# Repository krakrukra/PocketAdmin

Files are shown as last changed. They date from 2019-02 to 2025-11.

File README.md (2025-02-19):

# PocketAdmin  
  
#### Русская версия документации доступна [здесь](https://github.com/krakrukra/PocketAdmin/blob/master/extra/wiki/rus/README.md)  
  
This is a keystroke injection device (also called badusb). It is similar to a well-known  
[USB rubber ducky](https://shop.hak5.org/products/usb-rubber-ducky-deluxe) made by hak5, has rather extensive functionality, lower price  
and is also completely open source. It looks and feels like an ordinary USB flash drive,  
but acts as a keyboard that types in a preprogrammed payload. This payload can do anything  
from configuring a network to installing a reverse shell, since the device can basically  
do whatever an admin can with a terminal, but taking only a few seconds. This makes  
it a very powerful tool for automating sysadmin tasks or use in penetration testing.  
  
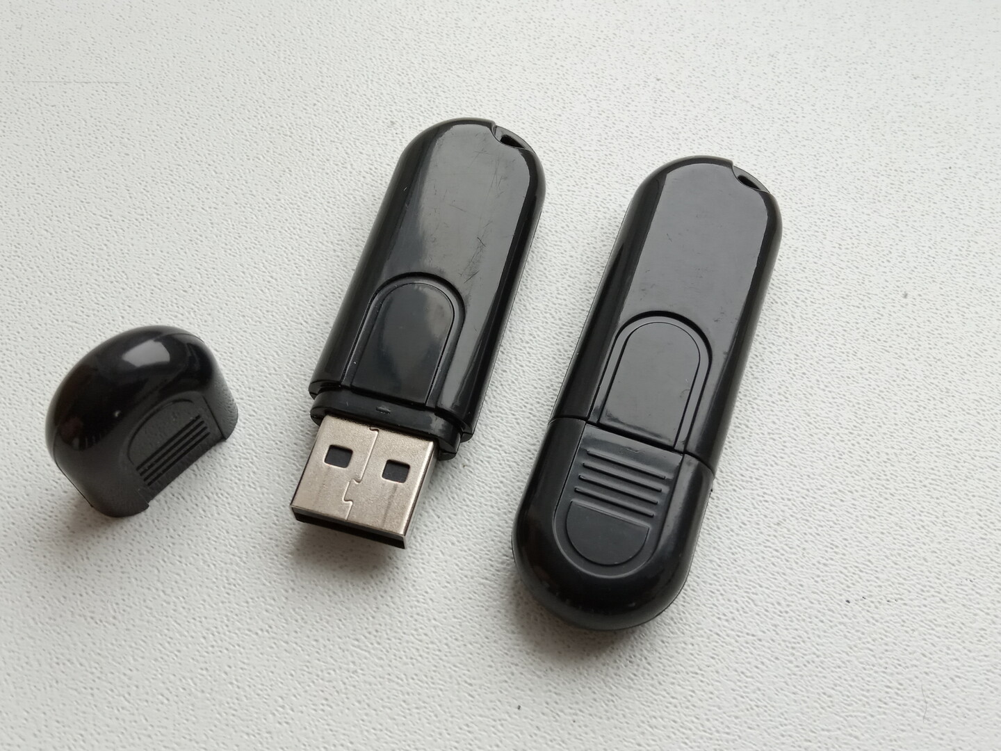
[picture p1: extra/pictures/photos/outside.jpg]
  
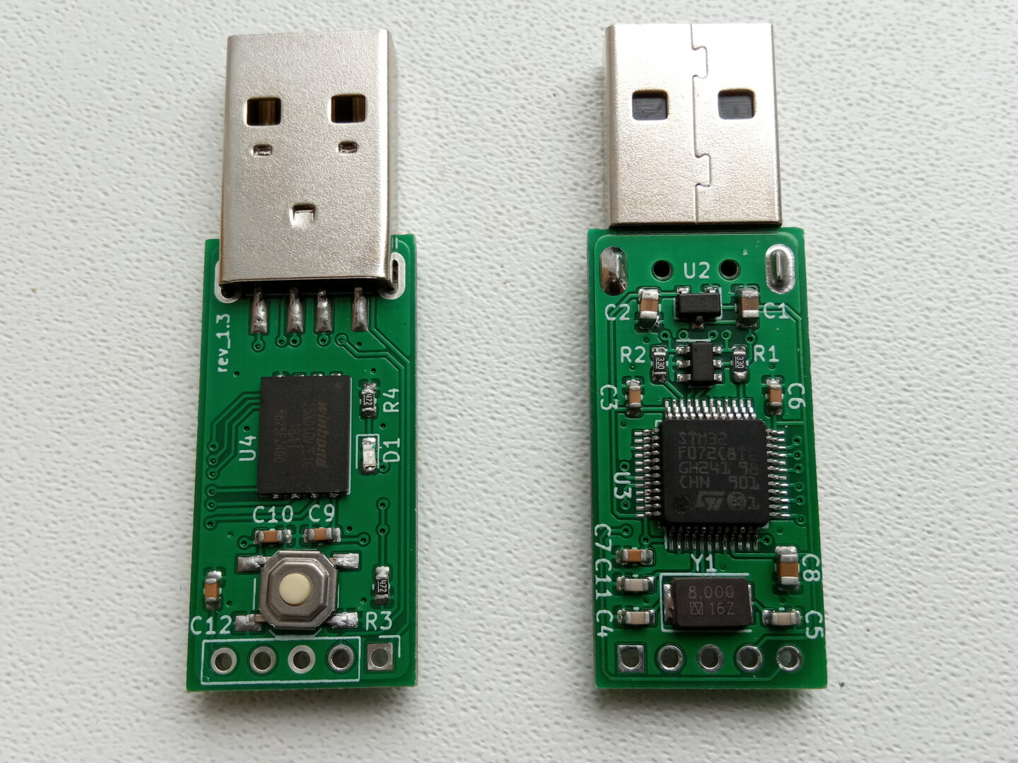
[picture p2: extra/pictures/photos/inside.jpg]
  
												        
Here is quick summary of how PocketAdmin is different from other badusb devices:  
  
1. Made from inexpensive off-the-shelf parts, with not only open source firmware,  
but hardware design files as well. This allows the user to do substantial  
modifications to the design, as well as provides an option to build your own units.  
  
2. Has a built-in interpreter (compatible with older ducky script 1.0) which takes text files directly,  
so you never have to install any encoder software and keep converting payload.txt to inject.bin.  
  
3. Has USB mass storage capability, allowing for better payloads; the memory chip is integrated,  
so there is no need to keep sticking SD card in/out of various devices while developing payloads.  
  
4. Has an OS detection mechanism, which allows you to store multiple on-insertion payloads  
simultaneously and have the device automatically pick the correct payload to run.  
  
5. You can save up to 17 extra on-demand payloads and execute them by tapping on a capslock key  
the appropriate number of times. You can also use this functionality for more convenient device  
operation, such as rebooting into mass storage or DFU modes without taking the device apart.  
  
6. Uses extended set of commands for extra functionality, such as: mouse control, commands to  
hold and release keys, dynamic delays, ability to repeat blocks of commands; you can have  
several non-modifier keys pressed simultaneously and you are not limited in keyword order or by  
a set of hardcoded key combinations, only by the maximum of 10 commands on a single line.  
  
7. User has several configuration options available, none of which require a firmware update.  
You can set which serial number and VID / PID values to use, how the device should show up  
(keyboard+mouse+disk or keyboard+mouse only), change keyboard layout, hide a particular  
memory region on the USB disk, show fake storage capacity, make disk read-only, etc.  
  
8. Has a special HID-only method of exfiltrating data into a file, known as keystroke reflection.  
It allows to extract small amounts of data even from very restricted and air-gapped computers.  
  
**CHECK THE [WIKI](https://github.com/krakrukra/PocketAdmin/wiki) FOR HOW-TO-USE INFORMATION**  
  
---
  
## hardware
  
project is designed using KiCad 6.0.11  
check KiCad pcb file for PCB manufacturing info  
check KiCad sch file + BOM.txt for component info  
  
Uses integrated full-speed (12Mbit/s) USB2.0 peripheral, with  
96MiB of available on-board flash memory for data storage;  
measured speeds for MSD access: read 800-850 KiB/s, write 700-750 KiB/s   
  
There is an LED and a pushbutton on the device. The LED is a mass storage  
status indicator, which lights up any time the device reads or writes flash  
memory. It is recommended to make sure this LED is turned off before pulling  
the device out of host machine, to prevent filesystem corruption.  
The pushbutton on the device is referred to as MSD-only button. Normally  
the payload is run whenever you plug the device into a PC. But if you press  
and hold this button while inserting the device, it prevents any keystrokes  
from being typed in and makes the device show up as a flash drive. It also  
prevents use of features like hidden region, fake capacity, read-only mode.  
  
Fully assembled unit has dimensions of 59x18x9mm and weight of 8 grams.  
When opening up the case, be careful no to break the plastic studs near  
the USB connector and at the opposite (from USB) end of enclosure.  
  
hardware programmer device used in this project is [ST-Link V2](https://www.aliexpress.com/item/1823628996.html)  
For instructions on how to build and flash the device go check this video:  
[https://www.youtube.com/watch?v=cfud5Dq_w2M](https://www.youtube.com/watch?v=cfud5Dq_w2M)  
  
## firmware  
  
Programming language used = C  
Flashing software used = openocd 0.12.0  
IDE used = emacs text editor + Makefile  
  
The firmware was developed on debian 11.3 system, using gcc-arm-none-eabi  
toolchain (compiler, linker, binutils) and it does use gcc specific extentions.  
it was successfully compiled and tested with arm-none-eabi-gcc version 12.2.1  
  
Depends on libgcc.a, which is included in this repository. Linker script,  
startup code and openocd configuration files are included here as well.  
  
Files usb\_rodata.h, hid\_rodata.h, msd\_rodata.h are not really  
headers, but integral parts of usb.c, main.c, msd.c respectively.  
they are not intended to be included in any other files.  
  
For easy in-field updates, you can use the DFU bootloader. There is a dfu  
firmware image available in **/firmware/firmware\_RRNNN.dfu** file. The name  
format is this: RR stands for board revision (13 = rev 1.3) , NNN stands  
for firmware version. For example, firmware\_13005.dfu means board  
revision 1.3, firmware version 5  

To automate firmware build process you can use make utility. If you  
open terminal in **/firmware/** directory, you could run these commands:  
  
> make  
> make upload  
> make dfu  
> make clean  
  
"make" will compile source code and create several files, among them  
is firmware.bin which contains firmware to flash. "make upload" will  
flash this file via St-Link V2 programmer. Make sure to connect the  
programmer to the board properly, before you plug it into PC and run the  
command. "make dfu" will create a DFU firmware image from firmware.bin  
which can be used later by DFU flashing software. "make clean" will  
delete all the compiled or temporary files created by previous commands.  
  
## directories info

#### /firmware/ ------------- contains makefile, linker script, source files; this is a build directory  
/firmware/cmsis/ ------- header files from CMSIS compliant [STM32F0xx standard peripherals library](https://www.st.com/content/st_com/en/products/embedded-software/mcus-embedded-software/stm32-embedded-software/stm32-standard-peripheral-libraries/stsw-stm32048.html)  
/firmware/stdlib/ ---------- standard statically linked libraries (libgcc.a)  
/firmware/openocd/ ------- standard configuration files for openocd  
/firmware/fatfs/ ---------- [chan fatfs](http://www.elm-chan.org/fsw/ff/00index_e.html) filesystem module + custom W25N01GVZEIG disk driver  
/firmware/usb/ ------------ USB system, MSD and HID class device implementation  
/firmware/main/ ------- main application file, interrupt vector table, IRQ handlers and startup code  
/firmware/dfuse-pack.py ------- python script to create .dfu firmware images  
/firmware/linkScript.ld ------- custom linker script for the GNU linker (ld)  
/firmware/Makefile ------- file used by GNU make utility for build automation  
/firmware/firmware_13NNN.dfu ------ pre-compiled firmware image in DfuSe format (STM32)  
  
#### /hardware/ ------------------- contains KiCad project, schematic, PCB files  
/hardware/PocketAdmin.symbols/ -- project specific symbol library  
/hardware/PocketAdmin.pretty/ --- project specific footprint library  
/hardware/gerbers/ ----------- gerber+excellon fabrication output files  
/hardware/BOM.txt --------- list of parts needed for DIY assembly  
  
#### /extra/ -------------------  contains pictures, payload files, documents, etc.  
/extra/pictures/ ---------------- photos and mechanical drawings  
/extra/wiki/ ------------------ github wiki pages  
/extra/payloads/ ----------- example and test payloads for PocketAdmin  
/extra/payloads/FeatureTesting/fingerprinterTest/fingerdb/ -- example OS fingerprint database  
/extra/payloads/FeatureTesting/layoutTest/kblayout/ --- alternative keyboard layout files  
  
## contact info  
  
if you have a problem / question / feature request, here are your options for contacting me:  
send me an email to krakrukra@tutanota.com  
create a new github issue (check [closed issues](https://github.com/krakrukra/PocketAdmin/issues?q=is%3Aissue+is%3Aclosed) first)  
also, you can check out my [youtube channel](https://www.youtube.com/channel/UC8HZCV1vNmZvp7ci1vNmj7g)  
  
For extra security, you could use my PGP public key saved in [/extra/pubkey.asc](https://github.com/krakrukra/PocketAdmin/blob/master/extra/pubkey.asc).

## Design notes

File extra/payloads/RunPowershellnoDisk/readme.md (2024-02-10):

This is a set of windows specific payloads, which will all work in  
HID-only mode. They are intended for use in situations where normal  
operation of built-in USB disk is not possible, eg due to security  
policies of whitelisting or complete blocking of USB storage devices.  
Those payloads will input a powershell script into the target machine  
some other way and then run it. It is up to the end user to replace  
default powershell scripts here with something more useful. If you  
want something to start off at, you can always search for scripts  
online. As an example, here is a collection of penetration testing  
scripts by Nikhil Mittal: [https://github.com/samratashok/nishang](https://github.com/samratashok/nishang)  
  
[HIDdownloadRun](https://github.com/krakrukra/PocketAdmin/tree/master/extra/payloads/RunPowershellnoDisk/HIDdownloadRun) downloads insert.ps1 file from a web server  
and runs it without requesting any administrative privileges, while  
hiding the powershell window as soon as possible for obfuscation.  
Default script is provided in payload directory, it creates a new  
file called "file.txt" on a desktop of a currently logged in user.  
In order to make this payload work, you will have to post insert.ps1  
script on a publicly available web server (eg github, dropbox, etc)  
and then write correct download link inside of your payload.txt  
  
[HIDrunlineScript](https://github.com/krakrukra/PocketAdmin/tree/master/extra/payloads/RunPowershellnoDisk/HIDrunlineScript) payload will type some powershell  
commands directly into the runline window as a script to execute.  
The size of a script like this must be small enough to fit there.  
Script runs without requesting administrative privileges, while  
hiding the powershell window as soon as possible for obfuscation.  
Default powershell script creates a new file called "file.txt"  
on a desktop of a currently logged in user.  
  
[HIDtypeAndRun](https://github.com/krakrukra/PocketAdmin/tree/master/extra/payloads/RunPowershellnoDisk/HIDtypeAndRun) payload will open a powershell window,  
pull it to the very bottom of the screen for obfuscation and  
then manually type a script and run it. You can use this payload  
in case your script is too long to fit in a runline window, and  
the internet connection is unavailable as well. Default script  
collects some information about target PC and saves it into  
"file.txt" on a desktop of a currently logged in user.

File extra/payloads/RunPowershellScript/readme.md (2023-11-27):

This is a set of windows specific payloads, which will all find the  
drive that has it's FAT volume label set to POCKETADMIN, and then go  
to this drive and start a powershell script from **insert.ps1** file.  
It is up to the end user to replace default powershell scripts here  
with something more useful. If you want something to start off at,  
you can always search for scripts online. As an example, here is a  
collection of penetration testing scripts by Nikhil Mittal:  
[https://github.com/samratashok/nishang](https://github.com/samratashok/nishang)  
  
Each subdirectory here contains a version of the payload that is  
slightly different from the rest. You should copy all the files  
from one particular subdirectory here to PocketAdmin's storage and  
set FAT volume label to POCKETADMIN before this payload can run.  
In order to change the FAT volume label on windows, you can just  
plug the device in, select the correct drive in the file manager  
(in "My Computer" -> "Devices and Drives") and press F2.  
Alternatively, in Linux you can use the fatlabel utility for that.  
  
[VisibleNonAdminScript](https://github.com/krakrukra/PocketAdmin/tree/master/extra/payloads/RunPowershellScript/VisibleNonAdminScript) payload runs the insert.ps1 script without  
requesting any administrative privileges, and also without any  
attempt to hide the powershell window. By default it only  
outputs a string into a terminal.  
  
[HiddenNonAdminScript](https://github.com/krakrukra/PocketAdmin/tree/master/extra/payloads/RunPowershellScript/HiddenNonAdminScript) payload runs the insert.ps1 script without  
requesting any administrative privileges, and also hides  
the powershell window as soon as possible for obfuscation.  
By default it creates a new file  called "testfile.txt" on  
a desktop of a currently logged in user.  
  
[DirectUACbypass](https://github.com/krakrukra/PocketAdmin/tree/master/extra/payloads/RunPowershellScript/DirectUACbypass) payload is trying to launch insert.ps1 script  
with administrative privileges, and also hides the powershell  
window as soon as possible for obfuscation. After a delay for  
UAC confirmation window to appear, payload tries to say YES.  
The currently logged in user has to have admin rights on the  
system in order for this to work. Default script creates a new  
file located at C:\Windows\adminonly.txt with some text inside.  
  
[SilentUACbypass](https://github.com/krakrukra/PocketAdmin/tree/master/extra/payloads/RunPowershellScript/SilentUACbypass) payload launches insert.ps1 script without requesting  
for admin rights explicitly, and instead attempts to do a silent UAC  
bypass inside the script (avoids showing a UAC confirmation window to  
the user). It also hides the powershell window as soon as possible for  
obfuscation. The currently logged in user still has to have admin rights  
on the system in order for this to work. Default script performs the UAC  
bypass, and then transfers execution to elevated.ps1 script, which is  
where end user has to put the code to be executed with admin rights. By  
default elevated.ps1 creates a file located at C:\Windows\adminonly.txt  
with some text inside. This payload might not work on windows versions  
older than windows 10 and might become obsolete in the future. It uses  
powershell command obfuscation in order to avoid detection by antivirus.  
  
[GetInformationScript](https://github.com/krakrukra/PocketAdmin/tree/master/extra/payloads/RunPowershellScript/GetInformationScript) is a demonstration script described in more  
detail in [this video](https://www.youtube.com/watch?v=o4rd-4753e0), though some of the commands shown  
there were replaced with more modern versions. It is an extention  
of DirectUACbypass basic script, showing how you can make it fit  
your needs in one particular situation and using some more tricks  
and commands in the process. Payload will collect some data from  
target machine and save it as exfil.txt on PocketAdmin's storage.  
It will only work if the currently logged in user has admin  
privileges, but this is a rather common situation.

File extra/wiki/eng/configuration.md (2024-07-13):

Besides simply reading a payload file and executing contained commands,  
PocketAdmin also provides several configuration options with which you  
can further specify how exactly the device should behave once plugged in.  
  
Such behaviour changes are done through the use of **pre-configuration**  
commands. Their format is similar to **special functionality** commands  
with no more than one command allowed on the same line, but they are  
different from all the normal commands because they act on the device  
itself and require to be executed before the device starts enumeration.  
Therefore, **pre-configuration** commands are not intended to be used in  
payload scripts, and instead must be placed in a separate config.txt file.  
Similarly, normal payload commands are not allowed inside of config.txt  
  
Pressing the MSD-only button prevents any on-insertion payload execution,  
but it also disables some **pre-configuration** commands. Specifically, these  
are "USE_HIDDEN_REGION", "SHOW_FAKE_CAPACITY **n**", "HID_ONLY_MODE"  
and "READ_ONLY_MODE" commands. The state of the button is read during  
device initialization, so you actually have to hold it down while inserting  
the device, and for 1-2 seconds after that. Rebooting into mass storage mode  
through long capslock toggle sequence (press 20 times or more) has the same  
effect and allows you to get normal access to device again.  
  
### Below is a complete list of all pre-configuration commands:  
  
* "VID **x**"   --- sets VID value for enumeration  
* "PID **x**"   --- sets PID value for enumeration  
* "SERIAL **s**"   --- sets serial number for enumeration  
* "HID_ONLY_MODE"   --- switches device to HID-only mode  
* "READ_ONLY_MODE"   --- makes USB storage read-only  
* "USE_FINGERPRINTER"   --- enables OS fingerprinter  
* "USE_LAYOUT **s**"   --- loads new keyboard layout from a file  
* "USE_HIDDEN_REGION"   --- make some memory unaccessible to host machine  
* "SHOW_FAKE_CAPACITY **n**"   --- lie to the host about device's capacity  
* "FIRST_INSERT_ONLY"   --- makes on-insertion payload run only one time  
* "MASS_ERASE"   --- unrecoverably erase all memory blocks  
  
---
  
1. With "VID **x**", "PID **x**", "SERIAL **s**" commands user can replace default  
VID, PID values and a serial number used for enumeration. VID, PID values  
are 4 digit hex numbers, while the serial number is a 12 character  
string, although only digits 0-9 and capital A-F letters are allowed in it.  
Any missing or invalid characters will be replaced by "0" in a serial number.  
Here are some examples: "VID 0x046D", "PID 0xC228", "SERIAL 32500A4B11FF"  
  
2. "HID_ONLY_MODE" command makes the device enumerate in HID-only mode (keyboard + mouse).  
Normally the device will enumerate in HID+MSD mode (keyboard + mouse + flash disk).  
It is useful in environments where USB storage devices are completely prohibited or  
whitelisted and you do not know which VID+PID values are allowed. So, by not showing  
MSD interface you can bypass such restrictions and still operate the device.  
  
3. "READ_ONLY_MODE" command makes the device's USB storage read-only (if available at all).  
Normally device's USB storage allows both read and write operations by the host PC. This  
command can be useful in case you want to protect files on your USB disk, eg. from being  
deleted by antivirus or some other software.  
  
4. "USE_FINGERPRINTER" command enables target OS detection.  
For more information check this [wiki page](https://github.com/krakrukra/PocketAdmin/wiki/fingerprinter)  
  
5. "USE_LAYOUT **s**" command replaces the default  
ASCII-to-HIDkeycode mapping with a new one.  
For more information check this [wiki page](https://github.com/krakrukra/PocketAdmin/wiki/layouts)  
  
6. "USE_HIDDEN_REGION" command reads the partition table (must be in MBR  
format), finds the first block right after the end of first partition and assigns  
it to be block number 0 for the host machine's read/write commands. This  
effectively makes the entire first partition and the partition table itself  
unaccessible by the host machine. In that case you can use the mass storage  
capability of the device, but without the end user seeing any payload, config,  
or other files that you use. Maximum size of hidden region is 16MiB, so you  
might need to edit the partition table before using this command. For example,  
if first 1MiB of memory contains the partition table and padding area, then  
the first partition of 15MiB or less can be hidden. If the partition is too large,  
this command is ignored.  
  
7. "SHOW_FAKE_CAPACITY **n**" command makes the device lie to the host machine  
about it's capacity. It takes a decimal number as an argument, which is new fake  
capacity in MiB (eg. "SHOW_FAKE_CAPACITY 2048" means pretend to be a 2GiB  
drive). The argument can be any value from 97 to 65535, otherwise the command  
is ignored. This command can be used if you want to make the device look more  
like an ordinary flash drive, since the real 96MiB of capacity can look suspicious  
to the end user. "SHOW_FAKE_CAPACITY **n**" and "USE_HIDDEN_REGION" do not  
interfere with each other, so you can use both at the same time, if necessary.  
  
8. "FIRST_INSERT_ONLY" command is yet another comouflage feature. With this  
command the device will create a new file in the root directory, called NOINSERT.  
If such file already exists when device is plugged in, then any on-insertion payloads  
will be blocked. This gives you an opportunity to run a payload on the first time  
the device is inserted, but then prevent payload execution until NOINSERT file is  
manually deleted. This can make the device less suspicious to the end user, since  
there will be no weird popup windows every single time that device is inserted.  
Note that the on-demand payloads are not blocked by this command.  
  
9. "MASS_ERASE" command erases all the data blocks on the device which contain,  
or have previously contained any data. The process will be started on the next  
time that device is plugged in, and it should take just a few seconds. After  
that, the device should show up as a flash drive again. Keep in mind, of course,  
that any stored files and partition table will be lost. This command is mainly  
intended to be a quick way to unrecoverably erase all the data on the device,  
without having to manually overwrite all logical blocks for a couple of times.

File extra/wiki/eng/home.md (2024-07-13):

#### Русская версия документации доступна [здесь](https://github.com/krakrukra/PocketAdmin/blob/master/extra/wiki/rus/home.md)  
  
By default PocketAdmin shows up as a compound device with HID  
(keyboard + mouse) and MSD (flash drive) interfaces. For the most  
basic use, there must be a FAT16 or FAT32 filesystem on the first  
partition (MBR partition table), and in the root directory there  
must be a payload.txt file, which contains plaintext commands that  
the device should execute. These commands will instruct the device  
to type in a specified string of characters, press a particular key  
combination or do something like wait for 500 milliseconds, etc.  
  
Normally the payload script (payload.txt) is run whenever you plug the  
device into a PC. This style of payload selection will be referred to  
as on-insertion payloads. Sometimes you do not want to run a payload  
every single time, for example, if you just want to edit some files.  
To prevent an on-insertion script execution you could use the MSD-only  
button. You need to hold it down, insert the device, wait around 1  
second after that, then release. In that case the device will not type  
anything in, and instead will show up as a normal flash drive, even if you have  
enabled HID or read-only modes. So you are always able to access the files.  
Another way to prevent on-insertion payloads is with the "ALLOW_EXIT"  
command, which allows you to avoid taking the device apart every time.  
  
Optionally, you can have a config.txt file alongside the payload.txt.  
This is the file where pre-configuration commands can be placed.  
PocketAdmin first reads this file, alters it's behavior based on what  
it found inside, and only then moves on to running some payload file.  
More advanced features like on-demand payloads, OS fingerprinter or  
using a different keyboard layout will require some extra files and  
directories stored on the device. You can find more info about that  
in dedicated wiki pages.  
  
#### Read other wiki pages:  
* [commands](https://github.com/krakrukra/PocketAdmin/wiki/commands)  
* [configuration](https://github.com/krakrukra/PocketAdmin/wiki/configuration)  
* [on-demand payloads](https://github.com/krakrukra/PocketAdmin/wiki/ondemand)  
* [OS fingerprinter](https://github.com/krakrukra/PocketAdmin/wiki/fingerprinter)  
* [keyboard layouts](https://github.com/krakrukra/PocketAdmin/wiki/layouts)  
* [example payloads](https://github.com/krakrukra/PocketAdmin/wiki/examples)  
* [DFU bootloader](https://github.com/krakrukra/PocketAdmin/wiki/bootloader)  
* [keystroke reflection](https://github.com/krakrukra/PocketAdmin/wiki/keyreflect)  
  
#### Some tutorial videos are available on my [youtube channel](https://www.youtube.com/channel/UC8HZCV1vNmZvp7ci1vNmj7g)

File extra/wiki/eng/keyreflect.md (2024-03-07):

Keystroke reflection is a method for exfiltrating data out of a host  
machine using only HID keyboard interface, rather than relying on USB  
mass storage or network. It is done by listening to incoming LED toggle  
commands sent to the device and interpreted in a special way.  
Specifically, once device receives a request from the host to toggle  
NumLock state it is treated as receiving a bit of value 1, and  
receiving a request to toggle CapsLock state is treated as receiving  
a bit of value 0. Bits are written from most significant bit first to  
least significant bit last in every byte.  
  
"KEYREFLECT_START" command makes the device start listening and writing  
incoming bits. Device should then make the PC send the key sequence,  
which will take some time. This can be done by running powershell or  
bash commands inside host's CLI. To mark the end of data host must send  
ScrollLock LED toggle request. Once the keystroke reflection sequence  
is over, "KEYREFLECT_SAVE **s**" command will save this data to a file  
inside /keyref/ directory. Name of the file can be specified as an  
argument, but this is optional. If specified, it must be in 8.3 format  
and the contents of it will be overwritten every time payload runs.  
If not set explicitly, device will make a new file with previously  
unused numeric name, eg. /keyref/002.ref, /keyref/003.ref, etc.  
  
Maximum size of reflection data received in one sequence is 512 bytes.  
If "KEYREFLECT_SAVE **s**" command is run before key sequence is over  
it will wait until ScrollLock toggle request is received or a limit of  
512 bytes is reached, whichever comes first. Only then the device will  
procede to save the data into a file. Keep in mind that the process of  
data exfiltration using this method is usually very slow, so only use  
it if you really have to avoid using mass storage or other means (eg.  
air-gapped and USB storage restricted PC).  
  
There is an [example payload](https://github.com/krakrukra/PocketAdmin/tree/master/extra/payloads/FeatureTesting/KeystrokeReflectionTest) for testing keystroke reflection on windows.

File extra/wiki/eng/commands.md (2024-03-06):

The command language used in payload files is based on older [ducky script 1.0](https://web.archive.org/web/20220816200129/http://github.com/hak5darren/USB-Rubber-Ducky/wiki/Duckyscript)  
originally made for the USB rubber ducky. This is to make the old rubber ducky  
payloads still work with PocketAdmin. There are, however, many differences and  
extentions, so it will not work the other way around.  
  
Here is a quick summary of the rules:  
  
1. Text encoding must be ASCII. Any symbol in a script that is  
not ASCII-printable causes the rest of the line to be ignored.  
Quotation marks used here are not parts of commands and  
are just used to indicate start and end of a command.  
  
2. All **special functionality** commands must be placed at the start of  
the line and terminated with a newline character. Other commands, such  
as **press key** or **mouse control** commands can be placed several times  
on the same line, with space characters separating them. In that case, all  
these key presses / mouse actions are considered to be applied simulteneously.  
  
3. Some commands take arguments, which follow the command keyword.  
These arguments will be denoted **n** for decimal numbers, **x** for hex  
numbers, **s** for strings or characters. The keyword and it's argument  
must be separated by exactly one space character.  
  
4. Hex arguments must have 0x prefix when used in scripts, but case of  
the letters doesn't matter (eg. 0x02ac, 0x02AC, 0x02aC are the same).  
Size of a decimal argument is allowed to be 1-6 symbols, of a hex  
argument 1-4 symbols, of a string argument 0-1000 symbols.  
  
5. a command keyword together with it's **numeric** argument are conidered  
as a single command (eg. "KEYCODE 0x04", "MOUSE_RIGHT 10"). You can have  
up to 10 different **press key** or **mouse control** commands on the same line.  
You can press up to 4 non-modifier keyboard keys simultaneously.  
  
6. There are no particular requirements for the order of commands on the  
same line (eg. "CTRL SHIFT a b" and "a SHIFT CTRL b" are the same). Also,  
you are not limited in which key combos are allowed and can use any  
arbitrary combination of **press key** and **mouse control** commands.  

### Below is a complete list of all payload commands:  
  
#### special functionality commands:  
* "REM **s**"  --- skips to the next line, used for comments  
* "DEFAULT_DELAY **n**"  --- sets how many milliseconds to wait after every command  
* "DEFAULTDELAY **n**"  --- same as "DEFAULT_DELAY **n**"  
* "ONACTION_DELAY **n**"  --- applies default delay, but only after some of commands  
* "DELAY **n**"  --- waits a specified number of milliseconds  
* "WAITFOR_INIT"  --- waits until host machine has finished device initialization  
* "WAITFOR_CAPSLOCK"  --- waits until user has manually toggled capslock 2 times  
* "WAITFOR_RESET"  --- waits until host machine resets the device (eg. on PC reboot)  
* "ALLOW_EXIT"  ---  gives user 1 second to toggle capslock, exits script if pressed  
* "REPEAT_START"  --- marks the beginning of a repeat block  
* "REPEAT **n**"  --- repeats previous command block for a specified number of times  
* "STRING_DELAY **n**"  --- sets how long to keep a key pressed/released with "STRING **s**"  
* "STRING **s**"  --- types in specified character string (ASCII-printable input)  
* "HOLD **s**"  --- keeps specified keys / mouse clicks continuously pressed  
* "RELEASE"  --- releases all keys / mouse clicks held by "HOLD **s**" command  
* "SETNUM_ON"  --- toggle NUMLOCK until it's LED is turned ON  
* "SETNUM_OFF"  --- toggle NUMLOCK until it's LED is turned OFF  
* "SETCAPS_ON"  --- toggle CAPSLOCK until it's LED is turned ON  
* "SETCAPS_OFF"  --- toggle CAPSLOCK until it's LED is turned OFF  
* "SETSCROLL_ON"  --- toggle SCROLLLOCK until it's LED is turned ON  
* "SETSCROLL_OFF"  --- toggle SCROLLLOCK until it's LED is turned OFF  
* "KEYREFLECT_START"  ---  marks the beginning of keystroke reflection  
* "KEYREFLECT_SAVE **s**"  --- saves keystroke reflection data into a file  
  
#### press key commands:  
* "GUI"  --- applies left GUI modifier key  
* "WINDOWS"  --- same as "GUI"  
* "CTRL"  --- applies left CTRL modifier key  
* "CONTROL"  --- same as "CTRL"  
* "SHIFT"  --- applies left SHIFT modifier key  
* "ALT"  --- applies left ALT modifier key  
* "RGUI"  --- applies right GUI modifier key  
* "RCTRL"  --- applies right CTRL modifier key  
* "RSHIFT"  --- applies right SHIFT modifier key  
* "RALT"  --- applies right ALT modifier key  
*   
* "KEYCODE **n**"  --- sends a key by HID keycode (decimal)  
* "KEYCODE **x**"  --- sends a key by HID keycode (hex)  
* "MENU"  --- key to open a menu (often the same as right click)  
* "APP"  --- same as "MENU"  
* "ENTER"  
* "RETURN"  --- same as "ENTER"  
* "DOWN"  
* "LEFT"  
* "RIGHT"  
* "UP"  
* "DOWNARROW"  --- same as "DOWN" 
* "LEFTARROW"  --- same as "LEFT"  
* "RIGHTARROW"  --- same as "RIGHT"  
* "UPARROW"  --- same as "UP"  
* "PAUSE"  
* "BREAK"  --- same as "PAUSE"  
* "CAPSLOCK"  
* "DELETE"  
* "END"  
* "ESC"  
* "ESCAPE"  --- same as "ESC"  
* "HOME"  
* "INSERT"  
* "NUMLOCK"  
* "PAGEUP"  
* "PAGEDOWN"  
* "PRINTSCREEN"  
* "SCROLLLOCK"  
* "SPACE"  
* "SPACEBAR"  --- same as "SPACE"  
* "TAB"  
* "F1"  
* "F2"  
* "F3"  
* "F4"  
* "F5"  
* "F6"  
* "F7"  
* "F8"  
* "F9"  
* "F10"  
* "F11"  
* "F12"  
* ASCII-printable characters, except space ("a", "b", "G", "/", etc)  
*   
* "KP_SLASH"  --- keypad "/"  
* "KP_ASTERISK"  --- keypad "*"  
* "KP_MINUS"  --- keypad "-"  
* "KP_PLUS"  --- keypad "+"  
* "KP_ENTER"  --- keypad ENTER  
* "KP_1"  --- keypad "1" or END  
* "KP_2"  --- keypad "2" or DOWNARROW  
* "KP_3"  --- keypad "3" or PAGEDOWN  
* "KP_4"  --- keypad "4" or LEFTARROW  
* "KP_5"  --- keypad "5"  
* "KP_6"  --- keypad "6" or RIGHTARROW  
* "KP_7"  --- keypad "7" or HOME  
* "KP_8"  --- keypad "8" or UPARROW  
* "KP_9"  --- keypad "9" or PAGEUP  
* "KP_0"  --- keypad "0" or INSERT  
* "KP_PERIOD"  --- keypad "." or DELETE  

#### mouse control commands:  
* "MOUSE_LEFTCLICK"  
* "MOUSE_RIGHTCLICK"  
* "MOUSE_MIDCLICK"  
*   
* "MOUSE_RIGHT **n**"  --- move mouse cursor right by **n** units  
* "MOUSE_LEFT **n**"  --- move mouse cursor left by **n** units  
* "MOUSE_UP **n**"  --- move mouse cursor up by **n** units  
* "MOUSE_DOWN **n**"  --- move mouse cursor down by **n** units  
* "MOUSE_SCROLLDOWN **n**"  --- scroll mouse wheel by **n** units towards the user  
* "MOUSE_SCROLLUP **n**"  --- scroll mouse wheel by **n** units away from user  
  
---
  
Below is a more detailed explaination for some commands:  
  
1. "WAITFOR_INIT" command is intended to be used at startup, as a first ever  
command to be run. It actively taps on capslock key and waits for host response.  
Once the host responds with a request to light up the capslock LED, this command  
makes sure that the capslock is turned off. If default HID+MSD configuration is  
used, then "WAITFOR_INIT" will also wait until at least 1 read command was sent  
to the MSD interface, making sure that it is configured as well. This allows you  
to make sure that the host is ready to receive keystrokes, before you actually try  
to send them. Even if there was a rather long startup delay because of drivers being  
installed, etc, your payload can run successfully on the very first insertion, without  
you having to hardcode a huge delay in the script and waste more time than necessary.  
  
2. "WAITFOR_CAPSLOCK" command waits until user manually taps capslock 2 times  
(on a real keyboard), and only then continues with the payload execution. This is  
useful when you do not know exactly how long should the device wait at a certain  
point in the script. For example, you might be starting up some program, or waiting  
for UAC prompt to show up, etc. Depending on the situation it might take a variable  
amount of time before the next part of the script should be executed. Also, you can  
use this command whenever you need to mix badusb input and manual input. For  
example, badusb is logging into some online account, but you need to solve a  
CAPTCHA; so you pause the payload and solve the CAPTCHA manually, then badusb  
can continue with the script. Or maybe you are in a BIOS boot menu, but you  
are not exactly sure in what order the drives will be placed; so you select  
the drive manually and continue, etc.  
  
3. "WAITFOR_RESET" command waits until the host machine sends a USB reset signal,  
and is mostly intended to detect a host reboot. Depending on the situation, target  
PC might take a variable amount of time to reboot, but once it reboots there is a  
very limited amount of time to enter the BIOS / boot menu, etc; this makes normal  
delays unsuitable for payloads which involve rebooting into BIOS. Keep in mind  
though, that if the device will be actually powered off, then script execution  
cannot continue. In that case you should use the OS fingerprinter to select  
appropriate BIOS-specific payload once the power is turned on again.  
  
4. "SETNUM_ON", "SETNUM_OFF", "SETCAPS_ON", "SETCAPS_OFF", "SETSCROLL_ON",  
"SETSCROLL_OFF" are commands which will toggle NUMLOCK, CAPSLOCK, SCROLLLOCK  
keys until their respective LED's are turned ON or OFF. After the necessary  
LED state is reached, execution moves to the next command in the script.  
These commands can be useful eg. when you want to use windows ALT codes, which  
need the NUMLOCK to be set ON to work reliably, or to make sure CAPSLOCK is  
turned off before you type some case-sensitive command.  
  
5. "ONACTION_DELAY **n**" command is similar to "DEFAULT_DELAY **n**", and is in  
fact it's alternative. That is, you cannot use them simultaneously and if one of  
these commands is encountered in the script, it overwrites any effect that the  
previous command had. Both commands are used to automatically insert a  
specified delay (in milliseconds) after subsequent commands. The difference  
is, "DEFAULT_DELAY **n**" inserts a delay after any script line whatsoever, including  
"DEFAULT_DELAY **n**" itself, "REM **s**", "DELAY **n**", empty lines, etc; while the  
"ONACTION_DELAY **n**" only adds delay after "STRING **s**", "HOLD **s**", "RELEASE",  
or any combination of **press key** and **mouse control** commands.  
"DEFAULT_DELAY **n**" command only exists for compatibility with old  
ducky script and is not recommended for use in your own (new) scripts.  
  
6. "ALLOW_EXIT" command provides a means to stop current payload execution. It  
waits for 1 second while watching for user-initiated capslock toggles. If capslock  
was pressed 2 or more times, then the payload script will be abandoned and the  
device will go back to idle state, waiting for user to select some on-demand  
payload. If capslock toggles were not detected during the delay, payload execution  
will continue. You should make sure that that the device was successfully  
initialized before this command is encountered. In fact, usually this command  
is most useful after some sort of dynamic delay, eg. "WAITFOR_INIT", "ALLOW_EXIT"  
sequence allows you to have a payload that can be blocked by continuosly tapping  
on capslock while inserting the device (so you don't have to take the device  
apart and use MSD-only button for this).  
  
7. "STRING_DELAY **n**" command provides you a capability to slow down the rate  
at which subsequent "STRING **s**" commands will be typing specified characters.  
Normally, the device will send one report with pressed keys, and in the next frame,  
that is, after 1ms it will send a report with keys being released. If for some  
reason the host machine cannot keep up with such typing rate, specifying a  
"STRING_DELAY **n**" will make the device press a key and keep it pressed for **n**  
extra milliseconds. After this, the key will be released and again the extra **n** ms  
delay will be inseted before the next character will be typed in.  
  
8. "STRING **s**" command only accepts ASCII-printable characters, max length of the  
string is 1000 characters. By default a US-compatible keyboard layout is expected.  
If you have a different layout you need to change this by "USE_LAYOUT **s**"  
pre-configuration command in config.txt; otherwise symbols from script will not be  
typed in correctly. If you do have a US-compatible layout but you want to type a  
string in a different language, you should set the GUI to use your desired language  
and then use "STRING **s**" command with ASCII symbols that are bound to the same  
physical keys as the symbols that you are trying to print. For example, if GUI is  
configured to have RU input, "STRING Dtkjcbgtl CNTKC" command will result in  
"Велосипед СТЕЛС" string typed. (because you have to press the same key to  
type 'l' or 'д', same key for 'k' or 'л', etc)  
  
9. Mouse control commands which have to do with moving the pointer or the wheel  
take decimal arguments, ranging from 0 to 127. These arguments are relative  
values which represent displacement from the previous location and are expressed  
in logical units. It is completely up to the host machine to decide what these  
values actually mean and what postprocessing should be done on them. For example,  
dispacement by 10 units might mean 10 or 20 pixels, depending on the sensitivity  
setting. Also, host postprocessing might result in eg. "MOUSE_RIGHT 100" not  
being equivalent to "MOUSE_RIGHT 10" executed 10 times in a row. That means you  
should be extra careful and make correct assumptions about target machine to use  
mouse control successfully. Commands which have to do with moving mouse pointer  
on different axies (or add scroll) can be combined on a single line, for example,  
"MOUSE_RIGHT 120 MOUSE_DOWN 35 MOUSE_SCROLLUP 47" is a valid command.  
  
10. Single ASCII-printable character commands are available, which will type  
out that character. The appropriate modifiers (left SHIFT and right ALT keys)  
are applied automatically. That is, both "m" and "M" commands send the same  
keycode, but for "M" SHIFT modifier will be used. This also means you must use  
lowercase letters for key combos such as "GUI r" ("GUI R" means "GUI SHIFT r").  
You can, however, add more modifiers, like this: "CTRL SHIFT t" or "GUI CTRL M"  
  
11. "KEYCODE **n**", "KEYCODE **x**" commands are available, in case you want to  
send a keystroke by HID keycode (eg. you might want to type a ASCII non-printable  
character). The acceped keycode values are from 0 to 221 (decimal).  
Some information about keycodes can be found in [this document](https://usb.org/document-library/hid-usage-tables-14), pages 89-96.  
It is possible to use modifier keys with it, for example: "CTRL SHIFT KEYCODE 23"  
  
12. "HOLD **s**" command applies to keyboard keys (both modifiers or not) and also  
to mouse clicks. It is used whenever you need some keys continuously pressed, eg.  
while in windows 10 language selection menu, opened with GUI + SPACE keys. This  
command also affects output of "STRING **s**" and also of any **press key** or  
**mouse control** commands. To release all the keys/clicks currently held down  
you should use the "RELEASE" command. If you want to release only some  
particular keys, you can use several "HOLD **s**" commands in a row, since they  
discard any previously held keys. For example, the following command sequence  
"HOLD f g" "DELAY 500" "HOLD f" "DELAY 500" "RELEASE" will keep both "f" and "g"  
keys pressed for 500ms, then release only the "g" key, and only 500ms later  
release "f" as well.  
  
13. "REPEAT **n**" command can repeat one or more previous commands for a specified  
number of times. If a block of commands is to be repeated, the beginning of this  
block should be marked by a "REPEAT_START" command. The size of a repeat block  
is unlimited, so it can span for the entire length of the payload script. Once the  
"REPEAT **n**" command is completed, the previous repeat block is over and a new  
"REPEAT_START" command is expected. In case a "REPEAT **n**" command is used  
without a script block beginning explicitly specified, only the command  
immediately preceding the "REPEAT **n**" will be repeated. Some examples:  
\
The following script will run 3 commands right before REPEAT for  
11 times (once normally + repeated 10 times):  
"REPEAT\_START"  
"STRING this command block of 3 commands is repeated"  
"ENTER"  
"DELAY 300"  
"REPEAT 10"  
\
The following script will run 1 command right before REPEAT for  
5 times (once normally + repeated 4 times):  
"CTRL ALT DELETE"  
"REPEAT 4"  
  
14. "KEYREFLECT_START" and "KEYREFLECT_SAVE **s**" commands are used for  
keystroke reflection. For more information check this [wiki page](https://github.com/krakrukra/PocketAdmin/wiki/keyreflect)

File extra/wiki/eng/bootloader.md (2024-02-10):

While it is possible to use hardware programmer St-Link V2  
for performing firmware updates, there is an alternative way.  
You may instead use the DFU bootloader and send new updated  
firmware directly over USB. To do so, you will need to install  
some dedicated software on your PC, plug the PocketAdmin into  
this same PC and make sure that your device is in DFU mode.  
Then, you feed a particular firmware image in DfuSe format to  
this dedicated software and wait for it to finish the update.  
The latest firmware image is available in the repository, in  
**/firmware/firmware_13nnn.dfu** file, where nnn is a number  
which stands for firmware version (eg. firmware_13000.dfu);  
  
There are 2 ways to enter DFU mode. If your device is already  
functional, you can get into DFU mode by performing a long  
capslock toggle sequence **twice**. That is, first time you tap  
on a capslock key 20 or more times in a row, device will reboot  
into MSD mode. You tap capslock 20 or more times again,  
and device reboots into DFU mode.  
If the previous firmware on the device is corrupted/nonexistent,  
you will have to first short out boot0 pin to 3.3V line, and  
only then plug the device in (it will enter DFU mode right away);  
This can be done at the programming holes, using a piece of metal  
wire or just with tweezers. The 2 holes you need to connect are  
in the corner of PCB and they both have round copper pads around  
them, square pad should be on the other side and is not used.  
  
You can check [this video](https://www.youtube.com/watch?v=t0oajBFZcZY) for a demonstration of  
both old and new firmware update procedures.  
  
---
  
#### linux (debian) DFU update procedure  
  
1. install dfu-util (sudo apt-get install dfu-util)  
2. download this repository (.zip) to your PC and unpack it  
3. open terminal window in /firmware/ directory  
4. connect the device to PC via USB port  
5. tap on capslock 20 times or more  
6. wait at least 5 seconds  
7. tap on capslock 20 times or more again  
8. run command: dfu-util -a 0 -D firmware_13nnn.dfu  
9. wait for update process to finish, pull the device out  
  
#### windows DFU update procedure  
  
1. download [DfuSe demo](https://www.st.com/en/development-tools/stsw-stm32080.html) software  
2. install it and start the program  
3. download this repository (.zip) to your PC and unpack it  
4. connect the device to PC via USB port  
5. tap on capslock 20 times or more  
6. wait at least 5 seconds  
7. tap on capslock 20 times or more again  
8. click on "Choose" button (bottom right)  
9. select the /firmware/firmware_13nnn.dfu file  
10. select "Internal Flash" as target region (Target ID = 00)  
11. click on "Upgrade" button (bottom right)  
12. confirm by clicking "yes"  
13. wait for update process to finish, pull the device out

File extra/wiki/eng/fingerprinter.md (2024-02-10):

The OS detection mechanism is based on the fact that different  
USB host drivers react differently to insertion of PocketAdmin.  
For every device the host machine sends a sequence of control requests.  
  
For example, a windows machine might send this:  
* GET DEVICE DESCRIPTOR  
* SET ADDRESS  
* GET DEVICE DESCRIPTOR  
* GET CONFIGURATION DESCRIPTOR  
* GET STRING DESCRIPTOR  
* GET DEVICE QUALIFIER  
* GET DEVICE DESCRIPTOR  
* GET CONFIGURATION DESCRIPTOR  
* GET CONFIGURATION DESCRIPTOR  
* GET STRING DESCRIPTOR  
  
While a linux machine might send:  
* GET DEVICE DESCRIPTOR  
* SET ADDRESS  
* GET DEVICE DESCRIPTOR  
* GET DEVICE QUALIFIER  
* GET DEVICE QUALIFIER  
* GET DEVICE QUALIFIER  
* GET CONFIGURATION DESCRIPTOR  
* GET CONFIGURATION DESCRIPTOR  
* GET STRING DESCRIPTOR  
* GET STRING DESCRIPTOR  
  
These sequences are persistent between different times you insert the  
device in, as well as different physical machines that a particular OS  
is installed on. This allows you to build up a database and store it on  
the device. Once device is plugged in, it can compare incoming sequence  
of control requests with all the presaved patterns and guess which USB  
driver is used by the host machine, which in turn identifies the OS.  
  
These patterns are saved in fingerprint files and consist of the data  
from 10 of the very first control requests sent by the host, namely  
bmRequestType, bRequest and wValue fields, which gives a total of 4  
bytes saved per request. The byte order is the same as in actual USB  
control request. Only bytes 0, 1 and 3 are compared for every 4-byte  
member in the array.  
  
---
  
If "USE_FINGERPRINTER" pre-configuration command is present in config.txt,  
device ignores payload.txt and instead chooses a payload file based on  
target machine OS. These OS specific scripts must be placed in /fgscript/  
directory and their names must be in 8.3 format with .txt extention. The  
only allowed characters in the name are lowercase letters a-z, uppercase  
letters A-Z, digits 0-9, underscore and dot symbols. The names are not  
hardcoded though, so as long as the OS name is 8 characters or less you  
can use it, eg. linux.txt, windows.txt, mac.txt, someOS.txt, HP_bios.txt;  
  
The way one of these files will be selected is this. Once you insert the  
device it will collect the host machine's fingerprint and save it into a  
file called CURRENT.FGP inside /fingerdb/ directory; if CURRENT.FGP file  
already exists and does not match collected fingerprint, the previous data  
will be moved into PREVIOUS.FGP file (overwriting it if necessary). Device  
will then search through all the directories inside /fingerdb/ and if it  
finds a matching fingerprint file in one of these directories, it will use  
the directory name as the name of the OS. If a matching fingerprint file  
was not found anywhere, payload script named other.txt will be executed.  
  
So, if you have enabled the OS fingerprinter and you plug the device into  
some host machine, it will always create a new CURRENT.FGP file with data  
collected on that machine. If you didn't have any fingerprints in the  
database, device will try to run /fgscript/other.txt upon insertion. At  
this point you can add this new CURRENT.FGP file into your database by  
saving it into an OS specific directory. Let's say that the host was a  
linux machine. In that case, you would move CURRENT.FGP to /fingerdb/linux/  
directory, and possibly rename it someting more descriptive, like lin0.fgp;  
Fingerprint file names must be in the same 8.3 format, with .fgp extention.  
From this point on, the device should find the matching fingerprint file in  
/fingerdb/linux/ directory, so it would know that the correct on-insertion  
payload is /fgscript/linux.txt;  
  
Keep in mind that fingerprints can be different for different versions  
of some particular OS, and can change with time. For example, if your  
windows 10 machine had an update which modified it's USB driver,  
the fingerprint will probably change too, so a new .fgp file would  
have to be added into the database. This is also the reason why you  
may need several fingerprint files for the same OS.  
  
The fingerprint is only collected once, when the device powers on. Any  
other events like rebooting the host machine or any other kind of reset  
which involves no poweroff will not result in a new fingerprint collection  
process, and will not invoke any on-insertion payload again. This also  
includes restart into MSD-only mode invoked by capslock toggle sequence.  
So, if you plug the device in before the host machine is powered on, the  
fingerprint collected will belong to the BIOS, not the OS, since this is  
the first piece of software that will enumerate the device.  
  
PREVIOUS.FGP file comes in handy in situations where you cannot collect and  
relocate/rename CURRENT.FGP file on the same machine, eg. target machine is  
locked in some way. So you first collect the fingerprint on the locked  
machine, which overwrites CURRENT.FGP; then you plug the device into your  
other machine. Since fingerprint collected on your machine does not match  
the fingerprint of the locked machine, CURRENT.FGP will be moved into  
PREVIOUS.FGP, and CURRENT.FGP will be overwritten with the latest data. Now  
you can put PREVIOUS.FGP into the right directory and give it an appropriate  
name. If you plug the device into your machine several times over, data in  
CURRENT.FGP will match the collected fingerprint, so the PREVIOUS.FGP will  
stay untouched (up until you plug the device into some new machine again)  
  
There is an example OS fingerprint database included in this repository,  
in [/extra/payloads/FeatureTesting/FingerprinterTest/fingerdb/](https://github.com/krakrukra/PocketAdmin/tree/master/extra/payloads/FeatureTesting/FingerprinterTest/fingerdb); though, it is not  
particulary hard to build your own.

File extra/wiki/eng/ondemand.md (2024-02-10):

Most badusb devices start executing a payload script once they are  
inserted into a target machine. In some sense, this is a perfect  
time to run a payload, since this is exactly the time when user can  
expect some kind of popup windows appear, the screen would not be  
locked and the user is not actively typing / clicking with any real  
HID input devices. However, this approach puts a limitation on the  
number of payloads that you can carry on the device simultaneously.  
  
In situations where you need more payload scripts (eg. one with a  
keylogger, other with reverse shell, third with data extraction)  
and when you also have an opportunity to select appropriate payload  
manually, you can use a different approach. This approach is called  
on-demand payloads (as opposed to normal on-insertion payloads).  
  
This new approach allows you to store up to 17 extra payload scripts  
in a dedicated /ondemand/ directory. The names of these payload files  
should be in the format "scriptNN.txt", where NN is a number from 3  
to 19, with the first digit set to 0 if necessary. That is, path to  
the file should be /ondemand/script03.txt, /ondemand/script04.txt,  
/ondemand/script05.txt, etc, going up to /ondemand/script19.txt.  
In order to call a particular script you should use the capslock key  
on a real keyboard, tapping on it the same number of times as is the  
number of payload script that you want to execute. So, if you want to  
call script05.txt, you would press the capslock key 5 times in a row.  
Once there was 1 second without any more capslock toggles, the device  
considers it to be the end of sequence and starts to execute whatever  
particular payload that you have selected. Once this payload script  
has finished execution, the device will go back to idle state, waiting  
for a new on-demand payload to be selected.  
  
If you will tap on capslock 1 or 2 times, then device will do nothing.  
A sequence of 20 or more capslock toggles will result in a special  
behaviour. The device will disconnect itself from the bus and reconnect  
as if MSD-only button was pressed. This effectively allows you to use  
MSD-only button without actually having to take the device apart and  
press the actual hardware button. If you input a sequence of 20 or more  
capslock toggles again, the device will enter a DFU mode, without any  
other way to come back except pulling the device out again.  
  
All the on-demand payloads work no matter if MSD-only button was used  
or not and are completely independent from all the other functions, eg.  
there is no difference if you have enbled OS fingerprinter, HID-only  
mode, etc. If the script file that you have requested was not found,  
the device will stay in the idle state, but sequences of 20 or more  
toggles will function even if there is no valid filesystem found on device.  
  
On-demand payloads will not work on macOS computers, as on that OS  
keyboard LED state is usually not shared between different keyboards.

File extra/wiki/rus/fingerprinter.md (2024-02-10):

Механизм работы сканера ОС основан на том факте, что разные USB драйверы  
реагируют по-разному на подключение PocketAdmin. Каждое устройство при  
подключении получает от компьютера последовательность запросов настройки.  
  
Например, компьютер с Windows может отправить это:  
* GET DEVICE DESCRIPTOR  
* SET ADDRESS  
* GET DEVICE DESCRIPTOR  
* GET CONFIGURATION DESCRIPTOR  
* GET STRING DESCRIPTOR  
* GET DEVICE QUALIFIER  
* GET DEVICE DESCRIPTOR  
* GET CONFIGURATION DESCRIPTOR  
* GET CONFIGURATION DESCRIPTOR  
* GET STRING DESCRIPTOR  
  
В то время как компьютер с Linux может отправить:  
* GET DEVICE DESCRIPTOR  
* SET ADDRESS  
* GET DEVICE DESCRIPTOR  
* GET DEVICE QUALIFIER  
* GET DEVICE QUALIFIER  
* GET DEVICE QUALIFIER  
* GET CONFIGURATION DESCRIPTOR  
* GET CONFIGURATION DESCRIPTOR  
* GET STRING DESCRIPTOR  
* GET STRING DESCRIPTOR  
  
Эти последовательности запросов не меняются от раза к разу, когда вы  
вставляете устройство, а также не различаются от одного компьютера  
к другому, до тех пор пока на них установлена одинаковая ОС.  
Этот факт позволяет вам создать базу данных и хранить ее на устройстве.  
При подключении устройство сможет запомнить входящую последовательность  
запросов и сравнить её с файлами уже сохраненными на устройстве, чтобы  
определить какой USB драйвер используется компьютером и так определить ОС.  
  
Эти файлы отпечатков ОС (fingerprint) состоят из данных полученных в 10  
самых первых запросах, отправленных компьютером. Конкретно это поля  
bmRequestType, bRequest и wValue, которые дают в общей сложности 4  
сохранённых байта на каждый запрос. Порядок байтов в файле такой же,  
как и в самом USB запросе. Только байты 0, 1 и 3 используются для  
сравнения каждого 4-байтового элемента в массиве.  
  
---
  
Если в config.txt присутствует команда предварительной конфигурации "USE_FINGERPRINTER",  
устройство игнорирует payload.txt и вместо этого выбирает файл рабочего скрипта на основе  
обнаруженной ОС. Эти предназнченные для ОС скрипты должны быть размещены в каталоге  
/fgscript/ и их имена должны быть в формате 8.3 с .txt расширением. Разрешенные символы  
в названии - это заглавные буквы A-Z, маленькие буквы a-z, цифры 0-9, знаки подчеркивания  
и точки. Имена этих файлов могут быть любыми, до тех пор пока вышеуказанные ограничения  
соблюдены. Например такими: linux.txt, windows.txt, mac.txt, someOS.txt, HP_bios.txt;  
  
Как только вы вставите устройство, оно запомнит полученную от ПК последовательность  
команд настройки (отпечаток ОС) и сохранит его в файл под названием CURRENT.FGP  
внутри каталога /fingerdb/; Если файл CURRENT.FGP уже существует и не соответствует  
только что собранному отпечатку ОС, старый CURRENT.FGP будет перемещен в PREVIOUS.FGP  
перезаписывая PREVIOUS.FGP если он уже есть. То есть, устройство будет хранить 2 самых  
последних отпечатка ОС, из 2 разных компьютеров в которые было подключено устройство.  
Затем устройство будет просматривать все подкаталоги внутри /fingerdb/ и если найдёт  
соответствующий файл с отпечатком ОС в одном из этих каталогов, он будет использовать  
имя каталога как имя ОС. Если соответствующего файла отпечатков так и не нашлось, то  
будет запущен скрипт под названием other.txt (адрес /fgscript/other.txt)  
  
Итак, если вы включили сканер ОС и подключили устройство к компьютеру, то всегда  
будет создаваться новый файл /fingerdb/CURRENT.FGP с отпечатком ОС который был  
собран на этой машине. Если у вас не было отпечатков ОС в базе данных, устройство  
попытается запустить рабочий скрипт /fgscript/other.txt; теперь вы можете добавить  
этот новый файл CURRENT.FGP в свою базу данных, перенеся файл в каталог конкретной  
ОС. Допустим, на компьютере был установлен Linux. В этом случае вы можете переместить  
файл CURRENT.FGP в каталог /fingerdb/linux/ и, возможно, переименовать его для большей  
ясности, например в lin0.fgp; Имена файлов отпечатков ОС должны быть в том же формате  
8.3, с расширением .FGP; С этого момента устройство должно находить соответствующий  
файл отпечатков в /fingerdb/linux/lin0.fgp, и будет использовать название каталога  
(linux) чтобы запустить рабочий скрипт по адресу /fgscript/linux.txt;  
  
Имейте в виду, что отпечатки ОС могут быть разными для разных версий  
какой-то конкретной ОС и могут измениться со временем. Например, если  
у вашего компьютера с Windows 10 было обновление, которое изменило его  
драйвер USB, отпечаток ОС скорее всего тоже изменится. Поэтому новый  
.fgp файл нужно будет добавить в базу данных. По этой же причине, вам  
могут потребоваться несколько файлов отпечатков для одной той же ОС.  
  
Отпечаток ОС собирается только один раз, когда устройство включается.  
Другие события, такие как перезагрузка компьютера или любой другой вид  
сброса USB устройства, который не приводит к отключению питания, не  
приведут к новому сбору отпечатка ОС или новому запуску рабочего скрипта.  
Перезапуск устройства в дисковый режим через нажатия CapsLock тоже не  
приводит к новому сбору отпечатка ОС. Это всё значит, что если вы  
вставите устройство до того, как компьютер будет включен, собранный  
отпечаток ОС будет принадлежать BIOS, а не ОС, так как именно BIOS  
раньше всех нашёл и настроил устройство.  
  
PREVIOUS.FGP бывает полезен в ситуациях когда нет удобной возможности  
скопировать CURRENT.FGP в базу отпечатков ОС на той же машине где он был  
собран, например если эта машина по какой-то причине заблокирована.  
В такой ситуации вы сначала собираете отпечаток ОС на заблокированном  
компьютере, это перезаписывает CURRENT.FGP; Затем вы подключаете устройство  
к своему компьютеру. Поскольку отпечаток ОС, собранный на вашей машине,  
не совпадает с отпечатком ОС заблокированной машины, старый CURRENT.FGP  
будет перемещен в PREVIOUS.FGP, а CURRENT.FGP будет перезаписан с самым  
последним отпечатком. Теперь PREVIOUS.FGP можно будет перенести в  
правильный каталог и дать ему подходящее имя. Если вы подключите  
PocketAdmin к своей машине ещё несколько раз, данные в CURRENT.FGP будут  
соответствовать собранному отпечатку ОС, поэтому PREVIOUS.FGP будет  
оставаться нетронутым (пока вы снова не подключите устройство к новой машине)  
  
В этом репозитории для примера есть образец базы данных отпечатков ОС:  
[/extra/payloads/FeatureTesting/FingerprinterTest/fingerdb/](https://github.com/krakrukra/PocketAdmin/tree/master/extra/payloads/FeatureTesting/FingerprinterTest/fingerdb)  
При необходимости эту базу несложно расширить самостоятельно.

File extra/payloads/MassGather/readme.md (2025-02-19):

This is a windows specific payload, which will gather various  
information about a target machine and it's user in a  
non-invasive way. That is, without installing or launching any  
other software that was not included in the target system.  
Collected data can be useful by itself or can later be used for  
developing a more specialized payload for this same machine.  
  
After insertion, device will execute commands from **payload.txt**  
file. This will bring up windows runline dialog and use it to find  
the correct USB drive based on FAT volume label (POCKETADMIN) and  
then start a powershell script contained in **insert.ps1** file.  
It will be launched with request for administrative privileges,  
so currently logged in user has to have admin rights for script  
to work properly.  
  
All the data collected will be saved in a zip file on POCKETADMIN's  
USB storage with a name in this format: YYYYMMDD_hhmmss.zip, where YYYY  
is the year, MM - month, DD - day of month, hh - hour of the day in  
24-hour format, mm - minute, ss - second of when insert.ps1 was launched.  
So, every time you plug the device in, a new zip archive will be created.  
Information collected includes web browser data (from firefox, chrome  
and edge as these are very popular), SAM and SYSTEM registry hives  
(which allows to extract password hashes for local user accounts), saved  
Wi-Fi profiles with passwords in cleartext, network configuration, names  
of local user accounts and groups, lists of installed applications and  
scheduled tasks, powershell command history for current user and list of  
files in his home folder, clipboard contents at the time of insertion  
(if it was text), generic information about the target computer and OS,  
lists of active processes and services, etc.  
  
Browser data includes cookies, bookmarks, download and browsing history,  
web form autofill data, browser-stored passwords, and some other things.  
For the most part it comes in a form of SQLite and JSON files. JSON can  
be viewed in a text editor or a web browser, while SQLite files can be  
read by specialized SQL database softwares (eg [sqlitebrowser](https://sqlitebrowser.org)). Some of  
the data inside those database files is encrypted, so you will have to  
make additional steps to get the data out and use it. In order to decrypt  
saved passwords you can use python scripts provided in payload directory,  
these are [firefox_decrypt.py](https://github.com/unode/firefox_decrypt) and **chrome_decrypt_v10.py**;  
These scripts are not necessary to extract the data from target machine,  
so you may not copy them to PocketAdmin's USB storage, but use them later  
to decrypt data on a different computer. Here are the example commands for  
how you can do that, assuming you unpacked the YYYYMMDD_hhmmss.zip file in  
the same directory where python scripts are located:  
  
> python3 firefox_decrypt.py YYYYMMDD_hhmmss/firefox/something.default-esr  
> python3 chrome_decrypt_v10.py -d YYYYMMDD_hhmmss/chrome  
> python3 chrome_decrypt_v10.py -d YYYYMMDD_hhmmss/edge  
  
Make sure to replace "YYYYMMDD_hhmmss" with your actual directory name and  
"something.default-esr" with the name of your actual firefox profile. As  
you can see chrome_decrypt_v10.py script works for both chrome and edge web  
browsers. For older versions of edge and chrome you may use the same AES256  
key saved in decrypted_key_v10.bin to decrypt cookie values as well. But  
be aware that since chrome version 127 cookies are encrypted with v20 method.  
  
SAM and SYSTEM files collected on a target machine can be used to extract  
LM and NT hashes for local user account passwords. For example, it can be  
done using a python script **pwdump.py** from a package called [creddump7](https://github.com/CiscoCXSecurity/creddump7);  
Those hashes may be used directly in some circumstances or be used for  
cracking the original local user passwords. For example, if you choose to  
crack passwords using [hashcat](https://hashcat.net/hashcat) utility you could run commands like this  
(assuming you are on a debian PC and have creddump7 already installed):  
  
> /usr/share/creddump7/pwdump.py SYSTEM SAM > hashlist.txt  
> hashcat -a 0 -m 1000 hashlist.txt wordlist.txt  
  
This sequence of commands will use pwdump.py script to extract LM and NT  
hashes from SYSTEM and SAM files and save the results inside hashlist.txt;  
Then hashcat will hash every line inside wordlist.txt and then check if  
those hashes match the ones you extracted. If a match is found, you have  
successfully found the right password. There are many ways of how you can  
get or generate a wordlist, as well as many other possible modes of  
operation for hashcat, so feel free to do more research on that if needed.

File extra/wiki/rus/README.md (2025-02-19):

# PocketAdmin  
  
Это устройство для программного ввода клавиш (также называется badusb). Оно похоже на  
известное устройство [USB rubber ducky](https://shop.hak5.org/products/usb-rubber-ducky-deluxe), сделанное командой Hak5, при этом имеет широкие  
возможности, меньшую цену и полностью открытые исходные файлы. Оно выглядит как самый  
обычный USB диск, но при этом работает как клавиатура, которая исполняет заранее записанную  
серию команд. Таким образом можно решать широкий спектр IT задач от настройки сети до  
установки удалённого доступа, так как устройство фактически может делать всё то же самое что  
и человек в интерфейсе командной строки, но намного быстрее. Поэтому оно хорошо подходит  
для автоматизации задач системного администратора или проверок систем на безопасность.  
  
  
  
  
Вот короткий список характеристик, которыми PocketAdmin отличается от других badusb устройств:  
  
1. Сделан из недорогих и доступных к покупке деталей, с открытыми исходными файлами, в том  
числе схемой и печатной платой. Это позволяет всем желающим делать значительные изменения в  
устройсте и при желании производить их самостоятельно.  
  
2. Устройство имеет встроенный интерпретатор команд (совместимый с ducky script 1.0), который  
читает команды напрямую в текстовом формате, что убирает необходимость устанавливать  
дополнительное ПО, например для преобразования payload.txt в inject.bin  
  
3. Имеется возможность работы как USB диск, что позволяет делать более полезные скрипты. Чип памяти  
встроен в плату, так что вам не придётся постоянно вставлять/доставать SD карту при разработке.  
  
4. Имеется возможность определения ОС, что позволяет сохранять сразу несколько скриптов работающих  
при подключении. Устройство само может выбрать подходящий для каждой ОС рабочий скрипт.  
  
5. Можно сохранить 17 дополнительных скриптов выполняемых по запросу. Запускать такие скрипты можно  
нажимая нужное количество раз подряд на клавишу CapsLock. Таким же образом можно облегчить работу  
с устройством, например перезагрузить его в режим USB диска или режим DFU не разбирая при этом корпус.  
  
6. Использует расширенный набор команд для достижения больших возможностей, например управление мышью,  
команды для зажатия клавиш, динамические задержки, возможность повторять блоки команд; возможность  
нажимать несколько клавиш (не модификаторов) одновременно и отсутствие ограничений на порядок команд  
в строке или ограничения возможных комбинаций клавиш.  
  
7. Есть возможность выбрать разные настройки устройства, без необходимости перепрошивки. Например,  
можно указать значения VID/PID, серийный номер устройства, режим подключения (клавиатура + мышь  
или клавиатура + мышь + USB диск). Можно поменять раскладку клавиатуры, скрыть часть памяти на  
USB диске от доступа ПК, показывать ложное значение ёмкости диска, разрешить только чтение, итд.  
  
8. Имеется особый способ сохранения данных в файл с использованием только HID интерфейса, известный  
как отражение нажатий. Он позволяет извлекать небольшие объёмы информации даже из очень строго  
настроенных и не имеющих доступа к интернету компьютеров.  
  
**ИНСТРУКЦИЯ ПО ПРИМЕНЕНИЮ ЕСТЬ НА [ВИКИ](https://github.com/krakrukra/PocketAdmin/blob/master/extra/wiki/rus/home.md)**  
  
---
  
## аппаратная часть  
  
проект разработан с использованием KiCad 6.0.11  
изучите pcb файл KiCad для информации по печатной плате  
изучите BOM.txt и sch файл KiCad для информации по деталям  
  
Используется встроенное переферийное устройство USB2.0 full-speed (12Мбит/с),  
а также чип памяти дающий ёмкость в 96МиБ для хранения файлов.  
Измеренная скорость доступа к диску: чтение 800-850КиБ/c, запись 700-750 КиБ/с  
  
На устройстве есть LED индикатор и кнопка. LED индикатор показывает статус флеш  
памяти. Он загорается каждый раз когда устройство читает или записывает информацию  
на USB диске. Для избежания порчи файловой системы рекоммендуется не извлекать  
устройство пока индикатор не потухнет. Кнопка на плате включает дисковый режим.  
Обычно рабочий скрипт включается каждый раз при подключении устройства, но если  
заранее нажать эту кнопку и удерживать во время подключения, то рабочий скрипт  
выполняться не будет. Вместо этого устройство будет подключено в режиме USB диска  
не используя функции скрытности и режим только чтение, игнорируя config.txt  
  
Полностью собранное устройство имеет размер 59x18x9мм и вес 8 грамм.  
При открывании корпуса будьте аккуратны, чтобы не сломать пластиковые  
штырьки рядом с USB коннектором и на противоположной от него стороне.  
  
Программатор используемый для прошивки устройства - [ST-Link V2](https://www.aliexpress.com/item/1823628996.html)  
Инструкции по сборке и прошивке устройства есть в этом видео:  
[https://www.youtube.com/watch?v=cfud5Dq_w2M](https://www.youtube.com/watch?v=cfud5Dq_w2M)  
  
## прошивка  
  
язык программирования = C  
ПО для прошивки = openocd 0.12.0  
среда разработки = emacs + Makefile  
  
Прошивка разработана на системе debian 11.3 с использованием пакета gcc-arm-none-eabi  
(компилятор, компоновщик, бинарные утилиты) и использует расширения компилятора gcc.  
Она была успешно скомпилирована и протестирована с arm-none-eabi-gcc версии 12.2.1  
  
Имеет зависимость от библиотеки libgcc.a, она содержится в репозитории. Скрипт  
компоновщика, стартовый код, и файлы конфигурации openocd также содержатся в нём.  
  
Файлы usb\_rodata.h, hid\_rodata.h, msd\_rodata.h на самом деле не заголовочные,  
а составные части usb.c, main.c, msd.c соответственно. Они не предназначены для  
включения ни в какие другие файлы.  
  
Для записи прошивки можно использовать DFU загрузчик. В репозитории есть dfu  
образ прошивки в файле **/firmware/firmware\_RRNNN.dfu**; название записано в  
таком формате: RR - это версия платы (13 = плата 1.3) , NNN - это версия прошивки.  
Например, firmware\_13005.dfu это файл для платы версии 1.3 с прошивкой версии 5.  

Для автоматизации процесса компиляции применяется утилита make. Если вы откроете  
командную строку в каталоге **/firmware/** вы сможете запустить эти команды:  
  
> make  
> make upload  
> make dfu  
> make clean  
  
"make" компилирует исходный код и создает несколько файлов, среди которых  
есть firmware.bin который и нужно записать в память устройства. "make upload"  
через программатор ST-Link V2 запишет этот файл. Для этого нужно заранее  
правильно подключить плату к программатору, а затем и сам программатор к ПК.  
"make dfu" создаёт из firmware.bin образ dfu для загрузчика, который потом  
можно будет использовать для прошивки без программатора. "make clean"  
удалит все временные и промежуточные файлы созданные предыдущими командами.  
  
## содержание каталогов  
  
#### /firmware/ ------------- содержит makefile, скрипт компоновщика, исходный код, промежуточные файлы  
/firmware/cmsis/ ------- заголовочные файлы из CMSIS библиотеки [STM32F0xx standard peripherals](https://www.st.com/content/st_com/en/products/embedded-software/mcus-embedded-software/stm32-embedded-software/stm32-standard-peripheral-libraries/stsw-stm32048.html)  
/firmware/stdlib/ ---------- стандартные статические библиотеки (libgcc.a)  
/firmware/openocd/ ------- стандартные файлы конфигурации для openocd  
/firmware/fatfs/ ---------- библиотека файловой системы [chan fatfs](http://www.elm-chan.org/fsw/ff/00index_e.html) + собственный драйвер W25N01GVZEIG  
/firmware/usb/ ------------ собственный USB стек, реализация устройств MSD и HID классов  
/firmware/main/ ------- основаная программа, таблица адресов прерываний, стартовый код, функции прерывний  
/firmware/dfuse-pack.py ------- скрипт в python для создания .dfu образов прошивки  
/firmware/linkScript.ld ------- специальный скрипт для GNU компоновщика (ld)  
/firmware/Makefile ------- файл используемый утилитой автоматизации GNU make    
/firmware/firmware_13NNN.dfu ------ заранее скомпилированный образ прошивки в формате DfuSe (STM32)  
  
#### /hardware/ ------------------- содержит KiCad проект, файлы схемы и печатной платы  
/hardware/PocketAdmin.symbols/ -- библиотека символов для схемы проекта  
/hardware/PocketAdmin.pretty/ --- библиотека деталей для платы проекта  
/hardware/gerbers/ ----------- gerber+excellon файлы для производства  
/hardware/BOM.txt --------- список деталей для самостоятельной закупки и сборки  
  
#### /extra/ -------------------  содержит картинки, примеры скриптов, документы, итд.  
/extra/pictures/ ---------------- фото и чертежи механических деталей  
/extra/wiki/ ------------------ страницы вики для github  
/extra/payloads/ ----------- примеры рабочих скриптов для PocketAdmin  
/extra/payloads/FeatureTesting/fingerprinterTest/fingerdb/ -- образец базы данных отпечатков ОС  
/extra/payloads/FeatureTesting/layoutTest/kblayout/ --- файлы раскладок клавиатуры  
  
## контактная информация  
  
Если у вас есть проблема / вопрос / предложение, то вот несколько способов связаться со мной:  
отправьте email на krakrukra@tutanota.com  
создайте новый вопрос на github (сначала проверьте [уже закрытые](https://github.com/krakrukra/PocketAdmin/issues?q=is%3Aissue+is%3Aclosed))  
также можно использовать соцсети, например мой [канал на youtube](https://www.youtube.com/channel/UC8HZCV1vNmZvp7ci1vNmj7g),  
[группу ВК](https://vk.com/krakrukra) или мой [телеграм канал](https://t.me/krakrukra)  
  
#### где купить:  
  
Купить можно напрямую связавшись со мной (например через email) или через авито:  
https://www.avito.ru/voronezh/tovary_dlya_kompyutera/virtualnaya_klaviatura_pocketadmin_2844411885

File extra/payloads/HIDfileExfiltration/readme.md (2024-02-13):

This is a windows specific payload, which will work in HID-only mode.  
It can be used in situations where normal operation of built-in USB  
disk is not possible, eg due to security policies of whitelisting or  
complete blocking of USB storage devices. This payload will upload  
files from the home directory of a currently logged in user to your  
dropbox account. It works by downloading a powershell script called  
upload.ps1 in the repository into the target machine and then running  
it. This script has to be modified and then actually posted on a web  
server where anyone can read it (eg on this same dropbox account).  
  
Before you can use the payload you have to make an account with  
dropbox and create a new dropbox app. All of this can be done  
through their website. You will also have to go to permissions tab  
for your app and enable any files.metadata and files.content access.  
  
You **must** then replace APP_KEY_HERE, APP_SECRET_HERE, REFRESH_TOKEN_HERE  
strings with correct values inside your upload.ps1 file in order to  
receive anything. Values of app_key and app_secret are available via  
dropbox webpage dedicated to your app. To get refresh token you will have  
to run interactive powershell script called get_refresh_token.ps1 and  
follow the instructions it provides. By default, hidden files and files  
larger than 200MiB are not transferred to save time and space on your  
dropbox storage, you can remove these filters from upload.ps1 if needed.  
  
After your script was modified so it actually connects to your specific  
dropbox app you will need to post it online. You can do it by uploading  
upload.ps1 file to your dropbox. Then navigate to this file, select it,  
click "Share" -> "Create and copy link" and paste this link into  
payload.txt file (instead of URL_OF_YOUR_SCRIPT_HERE string). You will  
have to also change &dl=0 parameter inside URL to &dl=1 to make it work.  
  
After all this was done, you can copy your payload files to PocketAdmin's  
storage. You only need payload.txt and config.txt, but can copy them all.  
From that point on payload should run successfully, but keep in mind that  
transferring large quantities of data can take some time.

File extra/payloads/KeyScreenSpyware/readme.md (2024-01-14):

This is a windows specific payload, which will install several  
softwares on the target machine, to make screenshots of user's  
desktop, log keystrokes and then periodically send collected  
data back to a specified dropbox account. It is described in  
more detail in [this video](https://www.youtube.com/watch?v=pKTy7eIpTOI).  
**UPDATE:** due to dropbox changing their authentication method the  
procedure of configuring upload.ps1 will be somewhat different now   
  
After insertion, device will execute commands from **payload.txt**  
file. This will bring up windows runline dialog and use it to find  
the correct USB drive based on FAT volume label (POCKETADMIN)  
and start a powershell script contained in **/scripts/insert.ps1**  
This script will then copy all the spyware files into a directory  
**C:\ProgramData\WindowsUserAssist**, start these softwares right  
away and also place a vbs script from **/scripts/autostart.vbs** into  
the current user's startup folder to restart spyware on every login.  
  
Before you can use the payload you have to make an account with  
dropbox and create a new dropbox app. All of this can be done  
through their website. You will also have to go to permissions tab  
for your app and enable any files.metadata and files.content access.  
You **must** then modify upload.ps1 script to make it work correctly.  
  
#### screen capture software  
  
Screen capture software is stored in **/binaries/scap.exe**, while  
it's source code is available in **/scap-src/** directory. Source code  
is not required for the actual execution of the payload, so you do  
not have to copy it into the PocketAdmin's USB storage. This software  
was compiled on a windows machine using MinGW compiler toolchain.  
  
It will make a screenshot of current user's desktop at least once  
per minute, but not more often than once in 15 seconds. Actions  
that can trigger a new screenshot capture are: mouse left click,  
keyboard ENTER press or 1 minute timeout. The screenshots will be  
in JPG format and placed in the directory containing a timestamp  
in it's name, in this format: "YYYY_MM_DD_HH", where YYYY stands for  
the year, MM - month, DD - day of month, HH - hour in 24-hour format;  
Screenshots themselves have timestamps in their names too, in the  
following format: "HH-mm-ss.jpg", where HH is hour in 24-hour format,  
mm - minute, ss - second of when the screenshot was taken.  
  
#### keylogger software
  
Keylogger software is stored in **/binaries/klog.exe**, while it's  
source code is available in **/klog-src/** directory. Source code is  
not required for the actual execution of the payload, so you do  
not have to copy it into PocketAdmin's USB storage. This software  
was compiled on a windows machine using MinGW compiler toolchain.  
  
It will capture user keystrokes and log them into a file inside  
a directory containing a timestamp in it's name, in this format:  
"YYYY_MM_DD_HH", where YYYY stands for the year, MM - month,  
DD - day of month, HH - hour in 24-hour format. This is the  
same directory name as is used by screen capture software.  
  
Keylog files have timestamps in their names too, in the  
following format: HH-00.txt, where HH is hour in 24-hour format,  
00 is a literal string (eg. "22-00.txt" or "23-00.txt", etc)  
More precise timestamps, along with what window were the keystrokes  
typed into and what language was selected are placed inside the  
text file. The keystrokes are mostly logged when the key is **released**,  
so if you hold a key down it will register as only one character typed.  
Modifier keys, such as CTRL, SHIFT, ALT, GUI are tracked on both press  
and release events, with "/" character prefix in case the key was  
released. For example, you might see this: [LCTRL]a[/LCTRL] for LCTRL-a  
key combo, or this: [LALT][F4][/LALT] for LALT-F4 key combo.  
  
#### uploader script
  
To upload all the collected data from target machine back to you,  
there is a powershell script stored in **/scripts/upload.ps1**  
Once started, it runs continuously, similar to other softwares.  
When it detects a hour-of-the-day boundary (eg time goes from  
13:59 to 14:00), the folder that screencapture and keylogger  
software have been using is now written completely and can be  
sent back to a remote server. This folder will then be compressed  
into a zip archive and sent out to a specific dropbox app, depending  
on **app_key, app_secret, refresh_token** values of your application.  
Both the original directory and the zip archive will be removed from  
target machine's local storage after the data was sent to dropbox.  
  
You **must** replace APP_KEY_HERE, APP_SECRET_HERE, REFRESH_TOKEN_HERE  
strings with correct values inside your upload.ps1 file in order to  
receive anything. Values of app_key and app_secret are available via  
dropbox webpage dedicated to your app. To get refresh token you will  
have to run interactive powershell script called get_refresh_token.ps1  
and follow the instructions it provides.  

#### stop the softwares
  
klog.exe, scap.exe and the powershell script will all show up  
in the task manager and can be stopped from there. Keep in mind  
that when **insert.ps1** script installs the spyware on the  
target PC it will rename executables to some more innocuous names,  
such as "UserAssist Klg Host" or "UserAssist Scc Host"; the uploader  
script will be named "Windows PowerShell", just like any other  
powershell instance that is running.

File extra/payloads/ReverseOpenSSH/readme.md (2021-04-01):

This payload is intended for establishing a reverse SSH tunnel  
from windows **target machine** to a **public machine** (with public  
IP address). Target machine requests from public machine that  
port forwarding should be established on a particular TCP port.  
Any kind of traffic destined to this TCP port will then be  
redirected through the secure tunnel to the target machine,  
where a target ssh server will be listening. So, if somebody  
has the right private key and initiates ssh connection to the  
right port on the public machine, they will be able to log into  
the target machine instead. This somebody is assumed to connect  
from another, **main machine** which runs on debian linux. Such  
setup will allow for remote command execution and SFTP file  
transfer even in situations where both main and target machines  
are in different LAN's and are unable to communicate directly.  
  
More information about the payload is available in [this video](https://www.youtube.com/watch?v=h9NPPq0q95o).  
This payload requires quite a bit of preliminary setup to work,  
so I encourage you to spend some time and learn all the details.  
  
#### preparations (short description)  
  
1. Rent a VPS from some hosting provider, make sure you select  
debian linux as it's operating system.  
  
2. Optionally, save IP of your public machine (VPS) into a  
local hosts file in **/etc/hosts**; Here it will be assumed  
that you did that, and you named your server **someVPS**.  
  
3. Download the whole repository, unzip it, navigate to the  
payload folder in a terminal.  
  
4. Use "sudo apt-get install openssh-client" command to  
install ssh client on the main machine.  
  
5. Run **keysetup.sh** bash script to generate id keys,  
host keys, authorized_keys and known_hosts files. All  
of the dedicated machine folders will be affected.  
  
6. Copy subdirectory called **publicMachine** to your VPS,  
eg. like this "scp -r ./publicMachine root@someVPS:/root"  
  
7. Connect to your public machine via ssh ("ssh root@someVPS"),  
go to publicMachine directory, run **configPublic.sh** as root.  
Confirm that you want to save firewall rules if asked.  
  
8. Optionally, install sudo and add username "user" to the  
**/etc/sudoers** file (on your VPS).  
  
9. Delete publicMachine directory from your VPS, reboot it  
with "systemctl reboot" command. You should be dropped back  
to the main machine's terminal after that.  
  
10. Go to **mainMachine** subdirectory, run **configMain.sh** script  
from there as a normal user, not root (use the same account that  
will log into public and all target machines later on).  
  
11. Go to **targetMachine** subdirectory and add your VPS  
IP address to insert.ps1 script, by replacing the  
default configuration string of "192.168.1.46".  
  
12. Mount your PocketAdmin's drive, eg. "sudo mount /dev/sda1 /mnt".  
That implies that device was assigned "sda" name on your machine.  
  
13. Copy all of the contents inside **targetMachine** subdirectory  
to USB storage of PocketAdmin (not the directory as a whole).  
  
14. Unmount your PocketAdmin's drive and set it's FAT  
volume label, eg. "sudo fatlabel /dev/sda1 POCKETADMIN"  
  
#### execution (short description)  
  
On insertion, **payload.txt** file opens up a windows runline  
dialog, where a command is typed in. This command will find  
the correct driveletter for PocketAdmin's USB storage and  
run an **insert.ps1** script from the root directory over there.  
It will be run with administrative privileges, so make sure  
that currently logged in user on target machine has that.  
  
insert.ps1 script will copy some of the official [Win32-OpenSSH](https://github.com/PowerShell/Win32-OpenSSH)  
binaries and scripts to local folder "C:\Program Files\OpenSSH",  
copy ssh configuration files to "C:\ProgramData\ssh", configure  
file permissions and firewall rules. It will also set up a new  
scheduled task for ssh client and a new windows service for ssh  
server, so that they both launch at every bootup of the target.  
  
Once insert.ps1 script execution is done, there will be a  
new file on PocketAdmin's USB storage, inside **/portusers/**  
directory. The name of this file will contain a port number,  
and inside will be a list of all local users on a particular  
target machine. This information can be used later when the  
main machine connects to your VPS, as you need to specify  
some port and username to log in as. Effectively, this way  
you can choose where to connect, VPS or a particular target.  
  
#### stream  
  
There is a directory called stream in this payload, which is  
not related to establishing a reverse shell between machines.  
Rather, this is an extention to an already established SSH  
connection and it is described in more detail in [this video](https://www.youtube.com/watch?v=BF4Q4MDFaKE).

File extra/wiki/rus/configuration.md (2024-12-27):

Помимо простого чтения файлов с рабочими скриптами и выполнения содержащихся там команд,  
PocketAdmin также имеет несколько вариантов настроек, с которыми вы можете более точно  
указать, как именно устройство должно вести себя после подключения.  
  
Такие изменения в поведении устройства осуществляются путем использования команд  
**предварительной конфигурации**. Их формат похож на команды **специальных функций**,  
где разрешена только одна команда на 1 строку. Однако, такие команды отличаются от  
всех обычных, потому что они действуют на само устройство и их необходимо выполнить до  
того, как компьютер начнет настройку вставленного устройства. Следовательно, команды  
**предварительной конфигурации** не предназначены для использования в рабочих скриптах,  
и вместо этого должны быть размещены в отдельном файле под названием config.txt.  
Точно так же команды из рабочих скриптов не допускаются внутри config.txt  
  
Нажтие кнопки дискового режима предотвращаяет запуск рабочего скрипта при подключении,  
но также и отключает некоторые команды **предварительной конфигурации**, а именно:  
"USE_HIDDEN_REGION", "SHOW_FAKE_CAPACITY **n**", "HID_ONLY_MODE" и "READ_ONLY_MODE".  
Состояние кнопки считывается во время запуска устройства, так что вам нужно будет  
удерживать её как во время вставления устройства, так и 1-2 секунды после этого.  
Перезагрузка в дисковый режим через многократное нажатие CapsLock (20 и более раз)  
имеет такой же эффект и позволяет снова получить полный доступ к устройству.  
  
### Ниже приведен полный список всех команд предварительной конфигурации:  
  
* "VID **x**"  --- Устанавливает значение VID для устройства  
* "PID **x**"  --- Устанавливает значение PID для устройства  
* "SERIAL **s**" --- Устанавливает серийный номер устройства  
* "HID_ONLY_MODE" --- Переключает устройство в режим только мышь+клавитура  
* "READ_ONLY_MODE"   --- делает USB диск доступным только для чтения  
* "USE_FINGERPRINTER" --- Включает сканер ОС  
* "USE_LAYOUT **s**" --- Загружает новую раскладку клавиатуры из файла  
* "USE_HIDDEN_REGION" --- Делает часть памяти на диске устройства недоступной для ПК  
* "SHOW_FAKE_CAPACITY **n**" --- Показывает компьютеру ненастоящий размер диска  
* "FIRST_INSERT_ONLY" --- Приводит к тому что рабочий скрипт запускается только 1 раз  
* "MASS_ERASE" --- Проводит полную очистку всех блоков памяти на диске устройства  
  
---
  
1. Команды "VID **x**", "PID **x**", "SERIAL **s**" заменяют значения используемые  
устройством по умолчанию. Значения VID, PID это 4-значные шестнадцатеричные числа,  
а серийный номер - строка из 12 символов, в которой разрешены только цифры 0-9 и  
заглавные буквы A-F.  Если какие-то символы в серийном номере отсутствуют или  
являются недопустимыми, то эти символы будут заменены на "0". Вот несколько  
примеров таких команд: "VID 0x046D", "PID 0xC228", "SERIAL 32500A4B11FF"  
  
2. Команда "HID_ONLY_MODE" указывает устройству работать только в режиме  
HID (клавиатура + мышь). Без этой команды устройство работает в режиме  
HID + MSD (клавиатура + мышь + USB диск). Это полезно в ситуациях когда на  
целевом ПК запрещены USB диски или же существует белый список разрешённых  
устройств, чьи VID+PID значения вы не знаете. Так что, не показывая дисковый  
интерфейс можно обойти подобные ограничения и продолжать работу с устройством.  
  
3. Команда "READ_ONLY_MODE" делает USB диск устройства доступным только для  
чтения (если он вообще доступен). Обычно встроенный в устройство USB диск  
исполняет команды компьютера и на чтение, и на запись. Это может быть  
полезным для защиты файлов на диске, например от удаления антивирусом.  
  
4. Команда "USE_FINGERPRINTER" позволяет определить установленную ОС.  
Для дополнительной информации можете изучить [эту страницу](https://github.com/krakrukra/PocketAdmin/blob/master/extra/wiki/rus/fingerprinter.md)  
  
5. Команда "USE_LAYOUT **s**" заменяет раскладку клавиатуры, то есть  
как именно устройство превращает ASCII символ в значение HID-код.  
Для дополнительной информации можете изучить [эту страницу](https://github.com/krakrukra/PocketAdmin/blob/master/extra/wiki/rus/layouts.md)  
  
6. Команда "USE_HIDDEN_REGION" считывает таблицу разделов (должна быть в MBR  
формате), находит первый блок памяти сразу после окончания первого раздела и  
назначает его блоком памяти номер 0 для команд чтения и записи. Это приводит  
к тому что весь первый раздел и сама таблица разделов становятся недоступными  
для компьютера. В этом случае вы сможете использовать USB диск на устройстве,  
но при этом конечный пользователь не увидит файлы с рабочими скриптами, настройками  
и прочим что использует устройство. Максимальный размер скрытой области составляет  
16 MiB, так что вам нужно будет обеспечить подходящую таблицу разделов перед тем  
как использовать эту команду. Например, если первый 1 мегабайт памяти занят  
самой таблицей разделов (+ пустая область), то тогда первый раздел должен быть  
15 MiB или меньше чтобы его можно было скрыть. Если область которую предлагается  
скрыть слишком велика, то команда игнорируется.  
  
7. Команда "SHOW_FAKE_CAPACITY **n**" указывает устройству сообщить ложную  
ёмкость диска. Она принимает десятичное число в качестве аргумента, которое  
будет новой ложной ёмкостью в MiB (например, "SHOW_FAKE_CAPACITY 2048" означает  
ложную ёмкость в 2GiB). Аргумент может быть любым значением от 97 до 65535, в  
противном случае команда игнорируется. Эту команду можно использовать, если вы  
хотите, чтобы устройство выглядело более похожим на обычный USB диск для  
конечного пользователя. "SHOW_FAKE_CAPACITY **n**" и "USE_HIDDEN_REGION" не  
мешают друг на другу, и их можно использовать одновременно, при необходимости.  
  
8. Команда "FIRST_INSERT_ONLY" - это еще одна функция скрытности. С этой  
командой устройство будет создавать новый файл в корневом каталоге, под  
названием NOINSERT. Если такой файл уже существует при подключении устройства,  
тогда исполнение рабочего скрипта при вставлении устройства будет заблокировано.  
Это даст вам возможность запускать рабочий скрипт только в первый раз когда  
устройство вставлено, но при последующем подключении рабочий скрипт запускаться  
уже не будет. Чтобы снова сработал рабочий скрипт при вставлении устройства,  
нужно будет удалить файл NOINSERT вручную. Так устройство будет выглядеть менее  
подозрительным для конечного пользователя, поскольку каждый раз при вставлении  
устройства там не будет никаких странных всплывающих окон. При этом, команда  
не мешает исполнению рабочих скриптов по запросу (через CapsLock)  
  
9. Команда "MASS_ERASE" стирает все блоки данных на устройстве, которое содержат,  
или ранее содержали какие-либо данные. Процесс будет запущен в следующий раз,  
когда устройство будет подключено, и это должно занять всего несколько секунд. После  
этого устройство должно снова отображаться как USB диск. Имейте в виду, конечно,  
что любые сохраненные файлы и таблица разделов будут потеряны. Эта команда в основном  
предназначена как быстрый способ, чтобы наверняка стереть все данные на диске,  
без необходимости вручную перезаписывать все логические блоки несколько раз.

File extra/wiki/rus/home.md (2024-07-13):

По умолчанию PocketAdmin работает как составное устройство с HID  
(клавиатура + мышь) и MSD (USB диск) интерфейсами. Для работы на  
диске устройства должна быть файловая система FAT16 или FAT32 в  
первом разделе (таблица разделов MBR) и в корневом каталоге там  
должен быть файл payload.txt, который содержит текстовые команды,  
которые устройство должно выполнить. Эти команды укажут устройству,  
например, ввести указанную строку символов, нажать определенную  
комбинацию клавиш или подождать в нужное время 500 миллисекунд, итд.  
  
Обычно рабочий скрипт (payload.txt) запускается при подключении  
устройства в ПК. Такой способ выбора скрипта будет называтся  
при подключении. Иногда вам не нужно будет запускать скрипт,  
например, если вы просто хотите отредактировать какие-то файлы.  
Чтобы предотвратить выполнение скрипта при подключении, вы можете  
использовать кнопку дискового режима. Вам нужно будет удерживать  
её нажатой, затем вставить устройство, подождать около 1 секунды,  
отпустить. В этом случае устройство не будет исполнять никакие  
скрипты и вместо этого сделает доступным USB диск, даже если вы  
включали режим HID-only или read-only. Поэтому вы всегда можете  
получить доступ к файлам. Ещё один способ предотвратить запуск  
рабочего скрипта это команда "ALLOW_EXIT", с ней вам не придется  
разбирать корпус чтобы достать до кнопки.  
  
При необходимости, в корневой каталог можно добавить файл config.txt;  
Это файл, в котором размещены команды предварительной конфигурации.  
PocketAdmin сначала читает этот файл, изменяет своё поведение в  
зависимости от того, какие команды внутри, и только затем переходит  
к запуску рабочего скрипта. Более продвинутые функции, такие как  
вызов рабочего скрипта по запросу, сканер ОС или замена раскладки  
клавиатуры требуют наличия дополнительных файлов и каталогов на  
диске устройства. Более подробную информацию об этом можно найти на  
отдельных страницах документации посвященных этому.  
  
#### Другие страницы документации:  
* [команды](https://github.com/krakrukra/PocketAdmin/blob/master/extra/wiki/rus/commands.md)  
* [настройка](https://github.com/krakrukra/PocketAdmin/blob/master/extra/wiki/rus/configuration.md)  
* [скрипты по запросу](https://github.com/krakrukra/PocketAdmin/blob/master/extra/wiki/rus/ondemand.md)  
* [сканер ОС](https://github.com/krakrukra/PocketAdmin/blob/master/extra/wiki/rus/fingerprinter.md)  
* [раскладки клавиатуры](https://github.com/krakrukra/PocketAdmin/blob/master/extra/wiki/rus/layouts.md)  
* [примеры скриптов](https://github.com/krakrukra/PocketAdmin/blob/master/extra/wiki/rus/examples.md)  
* [DFU загрузчик](https://github.com/krakrukra/PocketAdmin/blob/master/extra/wiki/rus/bootloader.md)  
* [отражение нажатий](https://github.com/krakrukra/PocketAdmin/blob/master/extra/wiki/rus/keyreflect.md)  
  
#### На моём [youtube канале](https://www.youtube.com/channel/UC8HZCV1vNmZvp7ci1vNmj7g) есть видео по применению устройства

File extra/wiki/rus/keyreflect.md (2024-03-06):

Отражение нажатий - это метод извлечения данных из компьютера с использованием  
только HID интерфейса клавиатуры, вместо USB диска или интернет соединения.  
Это делается путём прослушивания команд на переключение LED индикаторов,  
которые ПК отправляет устройству и интерпретации их особым образом. А именно,  
получение запроса на переключение индикатора NumLock считается за получение 1  
бита со значением 1, а получение запроса на переключение индикатора CapsLock  
считается как получение бита со значением 0. Биты заполняются по порядку от  
самого старшего первым, до самого младшего последним в каждом байте.  
  
Команда "KEYREFLECT_START" указывает устройству начать слушать и записывать  
биты данных. После этого устройство должно будет указать ПК чтобы он начал  
отправлять правильную последовательность нажатий клавиш, что займёт определённое  
время. Это можно сделать путём ввода команд powershell или bash в интерфейс  
командной строки. Для указания конца последовательности используется запрос на  
переключение индикатора ScrollLock. После того как последовательность завершена,  
команда "KEYREFLECT_SAVE **s**" сохранит полученную информацию в файл  
внутри каталога /keyref/. Название файла можно указать в аргументе команды, но  
это не обязательно. Если имя прямо указано, то оно должно быть в формате 8.3 и  
его содержимое будет перезаписываться каждый раз при выполнении скрипта. Если  
имя прямо не указано, то устройство создаст новый файл с ранее не использованным  
численным именем, например /keyref/002.ref, /keyref/003.ref, итд.  
  
Максимальный размер данных полученных в одной последовательности - 512 байт.  
Если команда "KEYREFLECT_SAVE **s**" запускается до того как последовательность  
завершена, то она сначала подождёт либо запроса на переключение ScrollLock,  
либо достижения лимита в 512 байт, в зависимости от того что случится раньше.  
Только после этого устройство перейдёт к сохранению данных в файл. Имейте в  
виду, что такой способ получения данных обычно очень медленный, так что его  
применение имеет смысл только в случаях когда обычные средства невозможны,  
например ПК с запретом на USB диски и без подключения к интернету.  
  
В репозитории есть [образец скрипта](https://github.com/krakrukra/PocketAdmin/tree/master/extra/payloads/FeatureTesting/KeystrokeReflectionTest) для использования отражения нажатий

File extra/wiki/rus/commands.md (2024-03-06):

Язык команд, используемый в рабочих (payload) файлах, основан на [ducky script 1.0](https://web.archive.org/web/20220816200129/http://github.com/hak5darren/USB-Rubber-Ducky/wiki/Duckyscript)  
изначально сделанном для USB Rubber Ducky. Это сделано для того чтобы старые  
скрипты по-прежнему работали с PocketAdmin. Однако изначальный язык получил  
много расширений и изменений, так что это не будет работать в обратную сторону.  
  
Вот краткое изложение правил:  
  
1. Кодировка текста должна быть ASCII. Любой символ в скрипте, который не  
является печатным в ASCII приводит к тому, что остальная часть строки  
игнорируется. Используемые здесь кавычки не являются частью команд и  
просто используются для обозначения начала и конца команды.  
  
2. Все команды **специальных функций** должны быть помещены в начало  
строки и заканчиваться символом новой строки. Другие команды, такие  
так как команды **нажатия клавиш** или **управления мышью** могут быть размещены  
несколько раз подряд на одной строке, разделенные пробелами. В таком случае все  
эти нажатия клавиш или действия мыши считаются сделанными одновременно.  
  
3. Некоторые команды принимают аргументы, которые следуют за ключевым словом  
команды. Эти аргументы будут обозначаться **n** для десятичных чисел, **x**  
для шестнадцатеричных чисел, **s** для строк или символов. Ключевое слово и  
его аргумент должны быть разделены ровно одним пробелом.  
  
4. Шестнадцатеричные аргументы должны иметь префикс 0x при использовании в скриптах,  
но заглавность буквы не имеет значения (например, 0x02ac, 0x02AC, 0x02aC одинаковы).  
Размер десятичного аргумента может быть от 1 до 6 символов, размер шестнадцатеричного  
аргумента от 1 до 4 символов, строковый аргумент может быть от 0 до 1000 символов.  
  
5. Ключевое слово команды вместе с ее **числовым** аргументом рассматривается  
как одна команда (например, "KEYCODE 0x04", "MOUSE_RIGHT 10"). Вы можете иметь  
до 10 различных команд **нажатия клавиш** или **управления мышью** в одной строке.  
Вы можете одновременно нажимать до 4 клавиш клавиатуры (не являющихся модификаторами),  
а также любую комбинацию клавиш модификаторов.  
  
6. Особых требований к порядку команд на одной и той же строке нет (например,  
"CTRL SHIFT a b" и "a SHIFT CTRL b" — это одно и то же). Также, нет ограничений  
в том, какие комбинации клавиш разрешены, вы можете использовать любую  
произвольную комбинацию команд **нажатия клавиш** и **управления мышью**.  

### Ниже приведен полный список всех команд для рабочих файлов:  
  
#### команды специальных функций:  
* "REM **s**"  --- переходит к следующей строке, используется для комментариев  
* "DEFAULT_DELAY **n**"  --- устанавливает, сколько миллисекунд ждать после каждой команды  
* "DEFAULTDELAY **n**"  --- то же самое, что и "DEFAULT_DELAY **n**"  
* "ONACTION_DELAY **n**"  --- применяет задержку по умолчанию, но только после некоторых команд  
* "DELAY **n**"  --- ждёт указанное количество миллисекунд  
* "WAITFOR_INIT"  --- ждёт, пока компьютер завершит инициализацию устройства  
* "WAITFOR_CAPSLOCK"  --- ждёт, пока пользователь вручную не нажмёт CapsLock 2 раза  
* "WAITFOR_RESET"  --- ждёт, пока компьютер не перезагрузит устройство (например, при перезагрузке самого ПК)  
* "ALLOW_EXIT"  --- даёт пользователю 1 секунду, чтобы нажать CapsLock, выходит из скрипта при нажатии  
* "REPEAT_START"  --- отмечает начало блока команд для повтора  
* "REPEAT **n**"  --- повторяет предыдущий командный блок указанное количество раз  
* "STRING_DELAY **n**"  --- устанавливает, как долго держать клавиши нажатыми/отпущенными с помощью "STRING **s**"  
* "STRING **s**"  --- печатает строку символов указанную в аргументе (в формате ASCII)  
* "HOLD **s**"  --- удерживает указанные клавиши клавиатуры/мыши зажатыми  
* "RELEASE"  --- отпускает все клавиши клавиатуры/мыши, удерживаемые командой "HOLD **s**"  
* "SETNUM_ON"  --- переключает NUMLOCK, пока не загорится его светодиод  
* "SETNUM_OFF"  --- переключает NUMLOCK, пока его светодиод не погаснет  
* "SETCAPS_ON"  --- переключает CAPSLOCK, пока не загорится его светодиод  
* "SETCAPS_OFF"  --- переключает CAPSLOCK, пока его светодиод не погаснет  
* "SETSCROLL_ON"  --- переключает SCROLLLOCK, пока не загорится его светодиод  
* "SETSCROLL_OFF"  --- переключает SCROLLLOCK, пока его светодиод не погаснет  
* "KEYREFLECT_START"  ---  начинает приём данных методом отражения нажатий  
* "KEYREFLECT_SAVE **s**"  --- сохраняет данные отражения нажатий в указанный файл  

#### команды нажатия клавиш:  
* "GUI"  --- нажимает левую клавишу-модификатор GUI  
* "WINDOWS"  --- то же самое, что и "GUI"  
* "CTRL"  --- нажимает левую клавишу-модификатор CTRL  
* "CONTROL"  --- то же самое, что и "CTRL"  
* "SHIFT"  --- нажимает левую клавишу-модификатор SHIFT  
* "ALT"  --- нажимает левую клавишу-модификатор ALT  
* "RGUI"  --- нажимает правую клавишу-модификатор GUI  
* "RCTRL"  --- нажимает правую клавишу-модификатор CTRL  
* "RSHIFT"  --- нажимает правую клавишу-модификатор SHIFT  
* "RALT"  --- нажимает правую клавишу-модификатор ALT  
*  
* "KEYCODE **n**"  --- нажимает клавишу чей HID-код указан (десятичный)  
* "KEYCODE **x**"  --- нажимает клавишу чей HID-код указан (шестнадцатеричный)  
* "MENU"  --- клавиша для открытия меню (часто то же самое, что от правого щелчка)  
* "APP"  --- то же самое, что и "MENU"  
* "ENTER"  
* "RETURN"  --- то же самое, что и "ENTER"  
* "DOWN"  
* "LEFT"  
* "RIGHT"  
* "UP"  
* "DOWNARROW"  --- то же самое, что "DOWN"  
* "LEFTARROW"  --- то же самое, что и "LEFT"  
* "RIGHTARROW"  --- то же самое, что "RIGHT"  
* "UPARROW"  --- то же самое, что "UP"  
* "PAUSE"  
* "BREAK"  --- то же самое, что и "PAUSE"  
* "CAPSLOCK"  
* "DELETE"  
* "END"  
* "ESC"  
* "ESCAPE"  --- то же самое, что и "ESC"  
* "HOME"  
* "INSERT"  
* "NUMLOCK"  
* "PAGEUP"  
* "PAGEDOWN"  
* "PRINTSCREEN"  
* "SCROLLLOCK"  
* "SPACE"  
* "SPACEBAR"  --- то же самое, что и "SPACE"  
* "TAB"  
* "F1"  
* "F2"  
* "F3"  
* "F4"  
* "F5"  
* "F6"  
* "F7"  
* "F8"  
* "F9"  
* "F10"  
* "F11"  
* "F12"  
* Печатные символы ASCII, кроме пробела ("a", "b", "G", "/" итд.)  
*  
* "KP_SLASH"  --- клавиша кейпада "/"  
* "KP_ASTERISK"  --- клавиша кейпада "*"  
* "KP_MINUS"  --- клавиша кейпада "-"  
* "KP_PLUS"  --- клавиша кейпада "+"  
* "KP_ENTER"  --- клавиша кейпада ENTER  
* "KP_1"  --- клавиша кейпада "1" или END  
* "KP_2"  --- клавиша кейпада "2" или DOWNARROW  
* "KP_3"  --- клавиша кейпада "3" или PAGEDOWN  
* "KP_4"  --- клавиша кейпада "4" или LEFTARROW  
* "KP_5"  --- клавиша кейпада "5"  
* "KP_6"  --- клавиша кейпада "6" или RIGHTARROW  
* "KP_7"  --- клавиша кейпада "7" или HOME  
* "KP_8"  --- клавиша кейпада "8" или UPARROW  
* "KP_9"  --- клавиша кейпада "9" или PAGEUP  
* "KP_0"  --- клавиша кейпада "0" или INSERT  
* "KP_PERIOD"  --- клавиша кейпада "." или DELETE
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

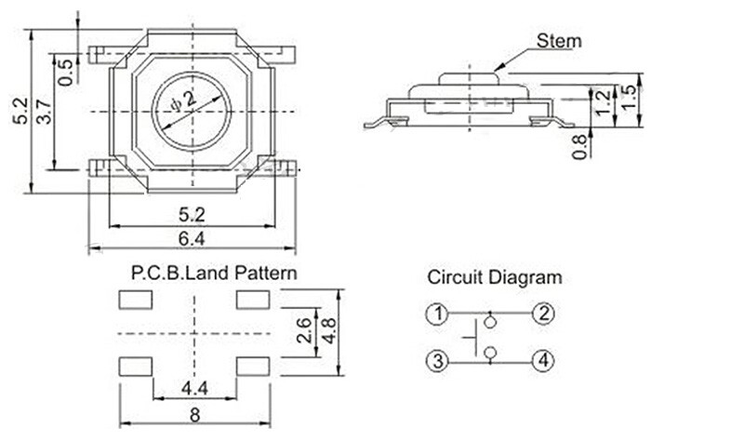
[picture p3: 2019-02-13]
extra/pictures/mechanical/TL3342_tactSwitch.jpg

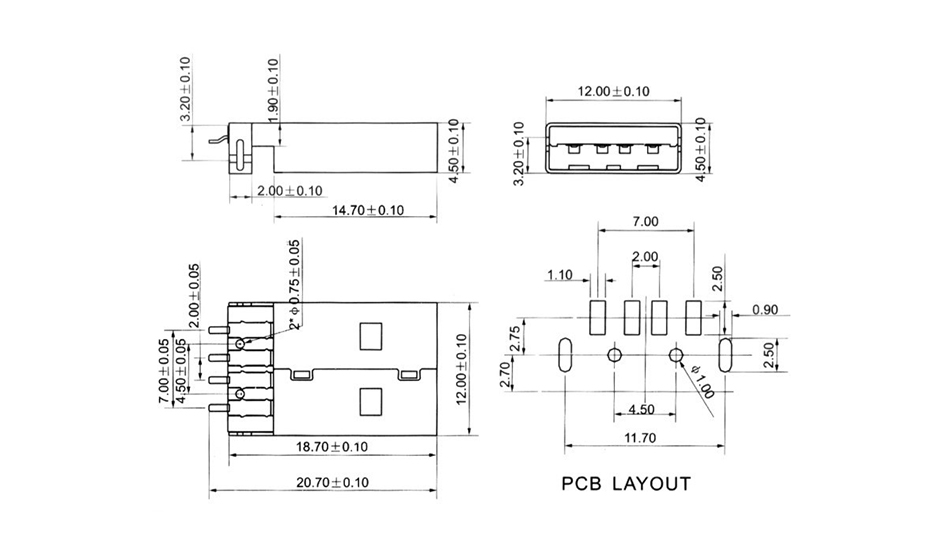
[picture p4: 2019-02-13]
extra/pictures/mechanical/G49_connector.jpg

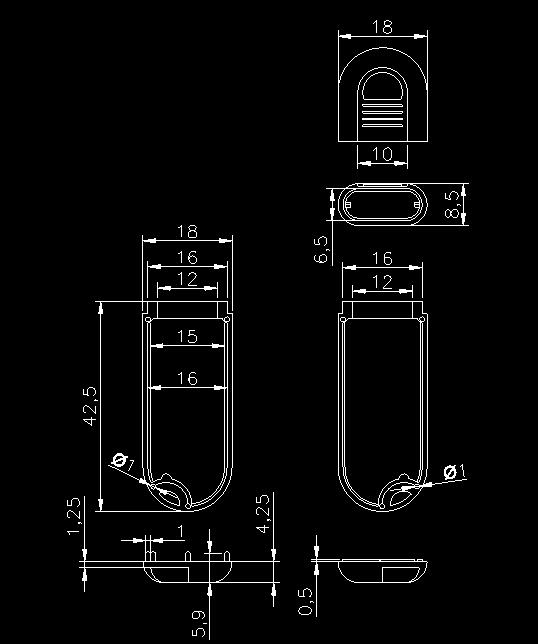
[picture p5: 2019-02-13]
extra/pictures/mechanical/AK-N-52_enclosure.png

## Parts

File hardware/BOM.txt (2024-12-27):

PocketAdmin_rev1.3 ----------------------- 28.11.2019 (dd.mm.yyyy)

all components, including mechanical ones are available on aliexpress.
example links to these items are for information purposes, check
for offers with better prices and shipping details yourself

quantities specified in this file are pieces per single PCB

STM32F072C8T6 microcontroller --- 1pcs

W25N01GVZEIG 128MiB flash memory chip --- 1pcs

IP4220CZ6 USB transient protection diode --- 1pcs

MCP1700-3302E/TT 3.3V LDO linear regulator --- 1pcs

0805 (2012 metric) 10% 16V X5R 10uF ceramic capacitors --- 3pcs

0603 (1608 metric) 5% 50V C0G 18pF ceramic capacitors --- 2pcs

0603 (1608 metric) 10% 50V X7R 100nF ceramic capacitors --- 7pcs

0603 (1608 metric) 5% 33 ohm resistors --- 2pcs

0603 (1608 metric) 5% 4.7k ohm resistors --- 2pcs

0603 (1608 metric) GREEN LED --- 1pcs

(5032 metric) NX5032GA STD-CSK-7 8MHz quartz crystal --- 1pcs

TL3342 tactile switch --- 1pcs
       you might want to choose similar ones with bigger height-off-PCB, up to 2mm (instead of 1.5mm with TL3342)
       https://www.aliexpress.com/item/32996664072.html

G49 black USB type A plug --- 1pcs
       https://www.aliexpress.com/item/32661919556.html

AK-N-52 black plastic enclosure --- 1pcs
       https://www.aliexpress.com/item/1005007727769388.html

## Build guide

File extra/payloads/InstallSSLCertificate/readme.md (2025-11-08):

This is a windows specific payload, which will install a new  
SSL root certificate into the target machine. This can be used  
to configure a bunch of clients to use your web server via  
secure connection, without having to buy a certificate from  
an existing authority. Alternatively, this can be used for  
penetration testing purposes, in case you want your web server  
to intercept HTTPS traffic that was originally intended for  
another server.  
  
After insertion, device will execute commands from **payload.txt**  
file. This will bring up windows runline dialog and use it to find  
the correct USB drive based on FAT volume label (POCKETADMIN)  
and then start a powershell script contained in **insert.ps1** file.  
It will be launched with request for administrative privileges,  
so currently logged in user has to have admin rights for script  
to work properly.  
  
Certificate to be installed on a target machine is located in  
**ca-certificate.pem** file inside the payload directory. You **must**  
replace the default file provided here with your own. To generate  
new SSL certificates you can use openssl utility. For convenience,  
some bash scripts are provided inside **rootCA** directory to  
automate the process. You should first run commands in  
**generateRootCA.sh** to create a new CA certificate and encrypted  
private key. Then, you can proceed to generating certificates for  
your web server. To do that, run **generateCertChain.sh** script.  
New web server certificate and private key will be created and  
moved to **website/ssl** directory.  
  
Besides adding a new SSL root certificate authority, **insert.ps1** script  
will also add new DNS entries into the windows **hosts** file, so make  
sure to modify default values used in **insert.ps1** with IP's and domain  
names of your specific web server. These DNS names must match  
the subjectAltName value specified in your website's SSL certificate.  
  
Note that the contents of **rootCA** and **website** directories are  
not meant to be copied to the PocketAdmin's USB drive. CA private key  
should be kept safe from any unauthorized access, and website  
directory contains configuration files for an example web server.  
This particular example payload expects that your web server is  
installed on a VPS with Debian Linux system. If that is the case,  
make sure you have packages apache2 and php installed there. Then  
you need to copy website directory from the payload into **/var/www/**  
directory on your Debian VPS, and configure your web server by  
running a bash script **/var/www/website/config/configureApache2.sh**

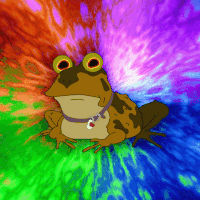
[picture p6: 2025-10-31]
extra/payloads/InstallSSLCertificate/website/html/toad.gif

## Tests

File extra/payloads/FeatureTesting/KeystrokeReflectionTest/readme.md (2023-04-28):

This is a windows specific payload, which is intended to show  
how keystroke reflection can be performed. You can directly copy  
all the files here to PocketAdmin's storage and it should work.  
  
The payload consists of invoking windows runline window and  
sending powershell commands through that 3 times in a row.  
First time it will get the username and save it into a temporary  
file on the host machine. Second time it will transform this  
file into a correct sequence of key presses and save it in a  
file again. Then payload enables keystroke reflection and runs  
a third line of powershell commands to actually send the key  
sequence specified in a file. This process usually takes some  
time. After the data transfer is over it will be saved on  
PocketAdmin's USB storage in a file /keyref/username.txt  
  
Since this payload uses HID_ONLY_MODE, you will need to use the  
MSD-only button (or long capslock toggle sequence) to make  
the device show up as a flash drive again.

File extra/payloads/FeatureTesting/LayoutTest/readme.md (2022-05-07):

This payload is intended for testing keyboard layout files, which is  
why the layout file database is stored here in /kblayout/ directory.  
You can directly copy all the files here to PocketAdmin's storage,  
then make sure some text editor is open before inserting the device.  
Device will try to type out a long string containing all of the  
available ASCII-printable characters.  
  
I recommend to first open the payload.txt file and copy-paste the  
string from there to serve as a reference. Then, you should move your  
cursor to the line below and plug the device in. If both PocketAdmin  
and target machine's GUI are configured to use the same keyboard  
layout, the string that was typed in by the device should be the same  
as the reference string above.  
  
If any characters are not the same as above you should either use a  
different layout file, or modify it so it works. In this example  
French layout is expected. To change it you should edit the  
config.txt and replace "fra_FR" with a different layout filename.  
  
Note: on Italian keyboard there is no way to input tilde and  
backtick symbols ( ~ and ` ), so spacebars are used instead.  
  
This payload also uses HID_ONLY_MODE, so you will need to use  
the MSD-only button (or long capslock toggle sequence) to make  
the device show up as a flash drive again.

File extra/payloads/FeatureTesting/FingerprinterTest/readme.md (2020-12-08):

This payload is intended for testing the OS detection mechanism.  
You can directly copy all the files here to PocketAdmin's storage,  
then make sure some text editor is open before inserting the device.  
Based on what the device thinks your OS is, it will type in  
"WINDOWS/LINUX/MAC/OTHER machine detected!"  
  
Since this payload does enable the fingerprinter, you will need to  
have a fingerprint database in /fingerdb/ directory on the device.  
Some example fingerprints are available in this payload directory,  
but it might be necessary to add your own fingerprint files there.  
To add a new OS called "someOS" you would place it's .fgp files in  
/fingerdb/someOS/ and a it's script file in /fgscript/someOS.txt  
  
This payload also uses HID_ONLY_MODE, so you will need to use the  
MSD-only button (or long capslock toggle sequence) to make  
the device show up as a flash drive again.

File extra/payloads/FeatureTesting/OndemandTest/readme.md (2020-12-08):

This payload is intended for testing on-demand payload functionality.  
You can directly copy all the files here to PocketAdmin's storage.  
  
Once you plug the device in, default on-insertion payload will open  
up notepad and do nothing else. If you input a sequence of several  
capslock toggles, device should call an appropriate payload from  
/ondemand/ directory, which will type out the following string:  
"this is an ON-DEMAND payload number **n**!", where **n** is the number  
of the payload script that was called.  
  
Since this payload uses HID_ONLY_MODE, you will need to use the  
MSD-only button (or long capslock toggle sequence) to make  
the device show up as a flash drive again.

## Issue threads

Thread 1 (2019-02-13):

general discussion

krakrukra, 2019-02-13:
this is created just in case you have some very small question or comment and you do not feel like creating a new github issue for it

SamPatt, 2019-02-23:
I noticed you using an OpenBazaar link. You can use a .com link to better share online.

https://openbazaar.com/store/QmeCrxkz8J1pvBx4nVE7EgZNkLfMftmKtz3dc5oo4bPgqr/pocketadmin-an-open-source-keystroke-injection-device-badusb

krakrukra, 2019-02-23:
thanks, I added the extra link

BlueskyFR, 2019-07-02:
Hey!
Can I build it myself?
If yes, what parts should I use and what is the flashing process?
Thanks in advance!

krakrukra, 2019-07-03:
Yes, you can. The parts are all listed in /hardware/BOM.txt (though, check the kicad files too)
and the flashing process (at least on a debian system) consists of installing openocd, make
and typing this in the terminal: make upload

but I probably will make a video about it on my youtube channel, to make things clear.

krakrukra, 2019-07-05:
OK, so here is a video on how to build it:
https://www.youtube.com/watch?v=cfud5Dq_w2M

kivik92, 2019-12-19:
Добрый день а как обстоят дела из keyboard_layout?
Тоесть если зарание неивзестно какая раскладка клавиатуры установлена?
То что с этим делать?

krakrukra, 2019-12-19:
если заранее не известно какая раскладка выбрана,  то нужную раскладку
надо выбрать каким-то способом. Например такой способ для windows 10
я показывал тут https://www.youtube.com/watch?v=o4rd-4753e0
смотреть нужно с 11:55 по 13:05

kivik92, 2020-01-01:
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

Ок. А если 3  языка установлено на ПК? То как быть в этом случае?

krakrukra, 2020-01-01:
ну клавиша END выберет самый нижний в списке. если не жать сразу ENTER,
а сначала нажать UPARROW, то будет выбран второй снизу итд.

krakrukra, 2020-01-01:
а хотя нет, только что проверил. нужно не стрелками выбирать а ещё раз
GUI SPACE  нажать. То есть через END выбрать нижний в списке, и с этого момента
нажать GUI SPACE 1 раз чтобы выбрать первый в списке, 2 раза чтобы выбрать
второй, итд.

yeboiiii, 2020-08-26:
Is it possible to use it to just open a cmd window with admin privileges? (without the privileges yourself)

krakrukra, 2020-08-26:
It might be possible, but I personally do not know how. It will probably be
something like silentUACbypass payload, where you take advantage of
task sceduler or some other thing. But this payload does require you to have
admin rights on the system.

TinSnail, 2020-09-04:
Hello, I have tried to alter the length of the serial number (using a v1.2 device) from:

[usb_rodata.h]
unsigned short StringDescriptor_1[13] =

to

 unsigned short StringDescriptor_1[21] =

The serial number length is still 13 characters when reviewed using ChipGenius

I then changed

[main.c]
extern unsigned short StringDescriptor_1[13];

to
extern unsigned short StringDescriptor_1[21];

The serial number still remained 13 characters.

It appears that there is a keyword to change the serial length:
checkKeyword("SERIAL ")

and looking into the config the serial is limited to 12 characters (v1.3 wiki):

https://github.com/krakrukra/PocketAdmin/wiki/configuration

Can the serial number be longer than 12 characters? If so what should be changed?

Thank you.

krakrukra, 2020-09-04:
Yes, it can be longer. You should also change the first element in the a StringDescriptor_1 array, from
0x031A to 0x032A (because LSB there actually specifies length of the descriptor in bytes, 42 in your case)

"SERIAL" pre-configuration command is actually changing the value of the serial number, not it's length.
This is so people can avoid flashing different firmware in case they want to change the serial number.
In your case, you should find a function in main.c called setSerialNumber() and replace 2 instances of
"i<12" to "i<20" and this command then should work properly for 20-character long serial number.

TinSnail, 2020-09-04:
Thank you. I will try this.

krakrukra, 2020-09-04:
Actually wait, I missed something. Are you trying to flash rev. 1.2 device with current firmware?
This will not work

TinSnail, 2020-09-04:
No it is old firmware. I can see the new firmware has the SERIAL feature. I have not moved to the new firmware as I need to read more about the differences. My apologies I have the modified old firmware on Debian an the new firmware on a windows machine. It took a while to find the serial string with checks using ChipGenius.

krakrukra, 2020-09-04:
Actually, here is the repository with firmware for rev 1.2 devices (inside /firmware_12005/):
https://github.com/krakrukra/12004-pocketadmin-wiki
This is the latest one for 1.2 devices that I have released. "SERIAL" command should actually be there.

TinSnail, 2020-09-04:
Thank you. I will try this method as the other embedded values, if required, can also be changed easily using the keyword method.

TinSnail, 2020-09-04:
WIth StringDescriptor_1 array, updated from 0x031A to 0x032A the new serial worked. Thank you.

yeboiiii, 2020-09-06:
Is it possible to combine a rubber ducky usb, a kill usb and a storage device (64 or 128gb) into one? (you would toggle it with a small switch that has 3 positions)

krakrukra, 2020-09-07:
It is possible, but it will not be practical.

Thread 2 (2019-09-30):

new 12004 firmware (FTL and big speed increase)

krakrukra, 2019-09-30:
The new 12004 firmware is a very big and desirable update.
However, it requires special care for people that decide to
update their older units on their own. What you need to do
is to make sure that all the bytes in flash memory are set to
0xFF. Since previous 12003 firmware did not implement FTL,
you could just overwrite all the bytes with the use of a hex
editor or some other software. Only after this is completed
you should proceed to updating the MCU with new firmware.

For now, both 12003 and 12004 firmwares are available in /extra/
directory. Should anything go wrong, you can always flash the
old 12003 version and the device will work.

Now, this firmware update significantly increases MSD access
speeds: from 223 KiB/s to 728 KiB/s for read access,
and also from  67 KiB/s to 110-150 KiB/s for writing.
The device now implements FTL (Flash Translation Layer), and
overprovisioning, which significantly reduces flash memory wear
and prolongs it's lifetime a lot. It does, however, mean that the
usable capacity will decrease, so you will only have about 24MiB
of space available to you after the update.

krakrukra, 2019-09-30:
This new release also opens up the road to move on to a more
modern memory chip and eventually boost the capacity to 96MiB
and further increase the write speed, likely up to 500KiB/s or more

Closed 2020-01-23.

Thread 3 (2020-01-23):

first rev 1.3 release

krakrukra, 2020-01-23:
New 1.3 revision of PocketAdmin is out! The wiki and other
documentation were updated, so if you have a previous 1.2
revision device (24MiB of capacity) you should keep in mind
that not all of the capabilites described there are available
on your device. The previous wiki and examples are now moved
to a separate repository. This release is using new hardware,
so you cannot directly apply new firmware to the old devices,
but there soon will be a backported 12005 firmware which will
give you most of the capabilities from the new revision,
exceptions being the status LED, higher access speed and extra
capacity. Instructions on how to flash this firmware will be
published in 12004-pocketadmin-wiki repository at some point.

Below is a summary of all important updates:

added a status LED which lights up whenever device receives
read/write commands. This gives user an indication that it
is too early to pull the device out and he should wait for
the LED to go off (to prevent filesystem corruption)

the usable capacity is increased from 24MiB to 96MiB; write
speed is also increased from 110-150KiB/s to about 750KiB/s
read speed is increased from 730KiB/s to 850KiB/s

DFU bootloader is now available for easy firmware updates;
You no longer need a harware programmer device for flashing,
but can flash new updated firmware images directly over USB.

fixed some bugs in the built-in script interpreter

last command in a payload file is now accepted even if it
had no proper newline termination (some users had their
scripts not run the last command because of this)

size of repeat blocks is now unlimited, "REPEAT_SIZE n"
command is now deprecated; you should  use "REPEAT_START"
instead to mark the beginning of a repeat block

argument to the "STRING" command can now be up to 1000
characters in length (instead of 400 previously)

you can now press up to 4 non-modifier keys simultaneously;
the order in which keywords appear does not matter anymore
(eg "CTRL SHIFT a b" is the same as "a SHIFT CTRL b"),
while previously non-modifier key command had to be at the end

mouse control is now available with commands such as
"MOUSE_LEFTCLICK", "MOUSE_RIGHTCLICK", "MOUSE_MIDCLICK",
"MOUSE_RIGHT n", "MOUSE_LEFT n", "MOUSE_UP n", "MOUSE_DOWN n",
"MOUSE_SCROLLDOWN n", "MOUSE_SCROLLUP n"

"HOLD" command can now hold not only modifiers, but also
non-modifier keys and mouse clicks;

the limit of keywords on one line is now increased from 5 to 10

there is now an "ONACTION_DELAY n" command, which is an alternative
to "DEFAULT_DELAY n"; the difference is, it only inserts default
delay after keyboard/mouse commands, and not after every single
line (which may be a comment, empty line, another delay, etc)

there is now a "STRING_DELAY n" command, which allows you to slow
down the rate at which "STRING s" command types in the characters.

there is now an "ALLOW_EXIT" command with which you can exit
current payload at some point.

new dynamic delays are available with commands such as
"WAITFOR_CAPSLOCK", "WAITFOR_RESET"; dynamic startup
delay is now much more reliable and is implemented using
a dedicated command "WAITFOR_INIT" instead of being
automatically placed before any on-insertion script

dynamic startup delay "WAITFOR_INIT" now also makes
sure that the capslock LED is turned off before the payload
script is executed, so the script now works correctly no
matter what the state of capslock was at the time of insertion

the "KEYCODE n" and "KEYCODE x" commands can now accept more
keycodes, from 0 to 221 (instead of from 0 to 101 previously)

keyboard boot protocol is now supported; that means the device
now can be used before some kind of OS was loaded, for example,
it can now open up a BIOS menu and change a boot device, etc.

you can now change the serial number of the device with
"SERIAL x" pre-configuration command

"MASS_ERASE" pre-configuration command is available, which will
quickly and unrecoverably erase all data blocks on the device

several camouflage features are now available with commands like
"USE_HIDDEN_REGION", "SHOW_FAKE_CAPACITY n", "FIRST_INSERT_ONLY"
pre-configuration commands; these can make the device appear
more like an ordinary mass storage flash drive to the end user

OS names which the fingerprinter uses are no longer hardcoded. You
can have user-defined names like "bsd", "hpBIOS", "someOS", etc;
only requirement is that the names should fit into FAT 8.3 format

OS fingerprinter now does not only create a new CURRENT.FGP file,
but also keeps a copy of the previously saved CURRENT.FGP inside
PREVIOUS.FGP; this is useful eg. for BIOS fingerprint collection,
where you might collect fingerprint on one machine, but rename and
place fingerprint file into the correct directory on another machine.

config.txt file is now more tolerant to small errors, eg.
invalid commands or empty lines are now ignored, but do not
cause subsequent commands to be ignored as well.

on-demand payloads are now available; that is, once some payload
script has finished it's execution, you can call another one by
tapping capslock a specified number of times; eg. tap on capslock
key 5 times calls /ondemand/script05.txt, tap capslock 7 times calls
/ondemand/script07.txt, and so on (from script03.txt to script19.txt)

20 or more capslock toggles in one sequence now results in detach-
attach sequence, with device reconnecting as if MSD-only button was
pressed; that is, you no longer have to take the device apart to
access actual hardware MSD-only button in case you need it;

krakrukra, 2020-01-26:
I have just now added the 12005 firmware and some
flashing instructions to the [12004-pocketadmin-wiki](https://github.com/krakrukra/12004-pocketadmin-wiki)
repository. This is where you should go if you wish to
 update your older rev 1.2 devices

Closed 2020-08-27.

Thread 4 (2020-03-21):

Unable to format

RChadwick7, 2020-03-21:
I made one of these a while ago, but was never successful flashing it, so I put it aside. I saw the Wili was updated, and gave it a try, and it worked! I plug it in, and it asks to format the drive. Unfortunately, it fails. What am I missing?

krakrukra, 2020-03-21:
Yes, I think I remember. You have built it before the 1.3 release, so you
should have 1.2 revision hardware, correct? The flashing procedure for
these is shown in this video (fragment from 0:00 to 4:43) :
https://www.youtube.com/watch?v=t0oajBFZcZY&feature=youtu.be
Is this the procedure you have followed?
Because you cannot run 13000 firmware on older hardware, in your case
you would need 12005 firmware

krakrukra, 2020-03-21:
If you followed the right procedure and it fails to format anyway, it might
be because the seller of the W25Q256FVFG memory chip did not ship it to
you pre-erased, as it should be. In this case, you should erase all the memory
yourself. If you flashed 13000 firmware into 1.2 device you should also erase
all memory before flashing the correct 12005 firmware. The easiest way to do
so is to flash 12003 firmware (disk size should become 32MiB), and then overwrite
all memory to 0xFF bytes using some hex editor (on linux I use hexedit). The process
could take quite a bit of time, like 10 min, because 12003 firmware was not very good.

RChadwick7, 2020-03-21:
I originally assumed I made some mistake building it, but it looks like you're right. I flashed 12003, and suddenly I had a 32MB flash drive. I was lazy, so I tried doing a long format, but that didn't work. I used HxD to flash FF's to everything, flashed 12005, and I have a 24MB drive now. Is it supposed to be 32MB?

RChadwick7, 2020-03-21:
Also, if new firmware won't be compatible with old hardware, is it easy/possible to upgrade the hardware to 1.3?

krakrukra, 2020-03-21:
Yes, it is supposed to be 24MiB. This is due to the fact that versions 12004 and up
have a Flash Translation Layer built in, and 8MiB are allocated for overprovisioning
and other stuff like that. The 12003 firmware did not have that, and directly
 translated logical block addresses into physical block addresses.

RChadwick7, 2020-03-21:
Great, thanks. I looked at the hardware, so I'm guessing it's not practical to physically upgrade :)

krakrukra, 2020-03-21:
Well yes, you would have to buy new PCB's and memory chips to upgrade the hardware.
Does your device seem to work OK with 12005 right now?

RChadwick7, 2020-03-21:
Yes, so far. I'm running H2testw (Endless verify), and it passed. Now I have to figure out how to use it :)

krakrukra, 2020-03-21:
OK, good

Closed 2020-03-21.

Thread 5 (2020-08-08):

Pocket Admin not readable by MacBook

Vanceagher, 2020-08-08:
Is the Pocket Admin supposed to be read by a MacBook? If not, how can I get this to work? Or will I have to use a Windows computer.

`Volume type : Physical Device
BSD device node : disk3
Connection : USB
Device tree path : IODeviceTree:/PCI0@0/OHC2@6
Writable : No
Is case-sensitive : No
Volume capacity : 100,925,440
Available space (Purgeable + Free) : 0
Purgeable space : 0
Free space : 0
Used space : 100,925,440
Owners enabled : No
Is encrypted : No
Can be verified : No
Can be repaired : No
Bootable : No
Journaled : No
Disk number : 3
Media name : Ordinary Flash Drive Media
Media type : Generic
Ejectable : Yes
Solid state : No
S.M.A.R.T. status : Not Supported
`

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

krakrukra, 2020-08-08:
It should be readable on macbooks, though it is not very extensively tested there.
First thing to do is to reformat the drive, make 1 partition and format it as FAT filesystem,
then try to plug the device in again.

krakrukra, 2020-08-08:
I have actually just now installed macos high sierra and noticed that default text editor (TextEdit)
adds a lot of extra data into the text files, so you might need a different text editor that does not
do that, in order to write payload files. But with properly written payload file the device has worked
OK on my machine, both for storage and keyboard.

Closed 2020-10-31.

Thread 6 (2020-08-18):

PocketAdmin v1.3 can't execute payload

leomacin, 2020-08-18:
Hai krakrukra, I'm glad to greet you.
I built PocketAdmin for a weekend project. I succeeded to flash the device both using ST-link and DFU mode. The device can't be detected by Windows 7-64bit and stated as Unknown Device. In Linux, Android, and Windows 10-64bit, it can be detected both as Keyboard and FlashDrive. I managed to format the drive to FAT and POCKETADMIN as label name.  I placed a simple payload
payload.txt
WAITFOR_INIT
DELAY 1000
GUI r

However, PocketAdmin doesn't execute the payload, even though it was detected as USB composite input and flash drive.
In addtion, whether I press the switch button or not, PocketAdmin still detected as Keyboard and Flash Drive.
do you have any solution?

thank you
Regards
Leo

krakrukra, 2020-08-18:
Regarding payload file not working, it might be because you are formatting the whole drive,
while you only need to format the first partition. You can follow the steps in the youtube video
here:   https://youtu.be/jhsEZJUVx_E   , to make an MBR partition table with 1 partition on windows 10 PC.
Ignore first 5 seconds of the video, your part starts with right-click on windows start menu. Also, make
sure that your filename extentions are shown, so your file is called payload.txt and not payload.txt.txt
I turn file extentions on in the video right after I place payload file on the drive.

Regarding switch button, it is in fact intended behaviour. Unless you are using HID_ONLY_MODE it
shows up as a composite device, but with MSD-only button held down it will not type anything.
Now, if MSD-button is not preventing payload execution, this is 100% a bad solder joint. Probably
at pin 12 of MCU, right next to capacitor C8. It sits in a nasty corner, so it is easy to make a bad
solder joint there if you are assembling the board for the first time.

As to windows 7, I will have to investigate that further. It is probably some drivers issue that
windows 7 has with composite devices. Meanwhile, you could try to use HID_ONLY_MODE
and see if it will work on your win7 machine. You could also try to change VID/PID  values,
or go to device manager (on win7 machine), select this "Unknown device" and choose
"delete device" somewhere in the menu. Next time you plug the device in, it might get recognised.
I remember from my testing that win7 tends to do things like assigning some driver to a device
based on VID/PID, and if it was not a correct driver loaded first time, it will not try to change
anything and just give errors. Eg. you had a keyboard with some VID before, now you plug in a
composite device with this same VID and that could cause a problem.

leomacin, 2020-08-18:
thank you. your first suggestion gives me a priceless clue. "make an MBR partition table with 1 partition"
Since my drive have been formated then I can't delete volume from disk management. As we know delete active partition is not supported in disk management. Therefore, It is my trick using diskpart
Open diskpart in cmd

`DISKPART> list disk

  Disk ###  Status         Size     Free     Dyn  Gpt
  --------  -------------  -------  -------  ---  ---
  Disk 0    Online          465 GB  1024 KB        *
  Disk 1    Online           96 MB      0 B

DISKPART> select disk 1

Disk 1 is now the selected disk.

DISKPART> clean

DiskPart succeeded in cleaning the disk.

DISKPART> create partition primary

DiskPart succeeded in creating the specified partition.

DISKPART> select partition 1

Partition 1 is now the selected partition.

DISKPART> active

DiskPart marked the current partition as active.

DISKPART> FORMAT FS=FAT QUICK

  100 percent completed

DiskPart successfully formatted the volume.

DISKPART>`

leomacin, 2020-08-18:
**UPDATE**

The Windows 7-64bit issue has solved. It was because I messed up with my USB driver and protocol in my PC by using VMware.
PocketAdmin works perfectly in the other Windows 7 machine. Even It works in Windows 7 inside VMware(from my messed up USB PC).

So, there is no issue anymore. I will close this github issue. Thank you

Closed 2020-08-18.

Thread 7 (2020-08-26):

Pocket Admin not typing anything

jwlanders1, 2020-08-26:
Hi, I just ordered these and I can’t figure out how to make them type. I followed the videos, but I can’t find anything on how to fix it.

krakrukra, 2020-08-26:
Does it show up as storage device? And also,
tell me which OS you are using and
what is the payload you are trying to run.

jwlanders1, 2020-08-26:
Yes it shows up as pocket admin but doesn’t type. I’m using windows 10. The
payload is just a test to open run and type cmd.  I’ve tested it in notepad
to see if it would type there, but it doesn’t.

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

krakrukra, 2020-08-26:
If you are on windows 10 it might be that you have file extentions turned off,
eg. file that should be called payload.txt is actually called payload.txt.txt
so, you could try to rename "payload.txt" to just "payload" and see if it helps.

also you did not mention any startup delay. try using this payload script:
WAITFOR_INIT
DELAY 1000
STRING test string into some text editor

make sure your cursor is in a notepad window before you plug the device in

jwlanders1, 2020-08-26:
it was “.txt.txt” didn’t even notice. thank you!

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

Closed 2020-10-31.

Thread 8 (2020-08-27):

Can you press the button without opening up the usb?

calegxm999, 2020-08-27:
You know how there is a button inside the usb to stop it from injecting the payload?
Can you press the button without opening up the usb?

krakrukra, 2020-08-27:
No, but this is why ALLOW_EXIT command was implemented.
I usually start a payload with this:
WAITFOR_INIT
ALLOW_EXIT

That makes the device wait for initialization time and then wait for
1 extra second. If you toggle capslock during this 1 second, payload
will not be run. So you can prevent payload execution by spamming
capslock key during device insertion.

calegxm999, 2020-08-27:
Thanks.......

Closed 2020-08-27.

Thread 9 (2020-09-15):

Button Not Working

Vanceagher, 2020-09-15:
I recently enabled the HID only mode but when I plugged in the USB while holding down the button inside, nothing happened. Before this I also notice that holding down the button while inserting the USB seemed to do nothing, the USB would still execute the on insertion payload.

krakrukra, 2020-09-15:
It might be that some solder joint got damaged. But maybe this is
just because the button is not held down long enough. Try to do this:
hold the button, plug the device in, wait for 5 seconds, release. Check
if it helped or not.

Vanceagher, 2020-09-15:
Just tried that, didn't seem to do anything, it must be a physical issue with the PocketAdmin.

krakrukra, 2020-09-15:
Well, then it is probably pin 12 on the microcontroller that got a damaged solder joint.
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
It is not really hard to fix, though I am not sure if you have a soldering iron around.

Good news is that this button is not very necessary for 1.3 revision devices. You can
get out of HID-only mode by tapping capslock 20 times or more (while device is inserted)
And if you want to prevent payload from being run you can use ALLOW_EXIT command.
That is, you start every payload with a sequence of WAITFOR_INIT and then ALLOW_EXIT
commands. This way you can prevent payload execution by spamming capslock while
you insert the device.

Vanceagher, 2020-09-15:
Great, the capslock trick worked.

krakrukra, 2020-09-15:
Though, if you are able to reflow that solder joint then you could restore MSD-button
operation as well. If you don't have that, maybe just press down on that pin with something
sharp, like tweezers or needle and it could restore the connection again

Closed 2020-10-31.

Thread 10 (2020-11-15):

Issues Running Payload On macOS Big Sur

iwantmyhatback, 2020-11-15:
Ive had my PocketAdmin for a little while but didn't get around to using it until the same day I upgraded my mac to the new "Big Sur" OS, so I'm not sure if this is a new issue or an old issue. I am having a similar issue to a previous one reported where the OS gave me an error when plugging in the drive:

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

- Ejecting results in ejection
- Ignore results in the drive only showing unmounted in disk utility
- Initializing allows me to see the drive in the disk utility allegedly mounted as `disk2` but i am unable to interact with it or even see the disk in the `/Volumes` directory.

I see that in the previous issue with the drive not being recognized by mac the instructions you provided there was to format the visible drive as an FAT-32 partition, but the person who reported the issue didn't reply so I'm not sure what happened in that case. I followed your advice (also making the required selection to format it as MBR). I had to change the name of the drive to "USBDRIVE1" as it wouldn't allow me enough characters to name it "Ordinary Flash Drive Media" on the macOS disk utility. (Noting that incase it may be causing an issue)

 The disk now shows up as:

` /dev/disk2 (external, physical):`
`   #:                       TYPE NAME                                   SIZE             IDENTIFIER`
`   0:                       FDisk_partition_scheme              *100.9 MB     disk2`
`   1:                       DOS_FAT_32 ⁨USBDRIVE1⁩               100.9 MB     disk2s1`

I am able to interact with the drive now and it mounts without error, but the USB features do not seem to be in effect anymore. I do not get payload execution upon insertion, and toggling the caps lock key has no effect on the drive when it is inserted. To test i am trying to use the following simple payload:

`WAITFOR_INIT`
`DELAY 1000`
`ALLOW_EXIT`
`DELAY 1000`
`GUI SPACE`
`DELAY 1000`
`STRING terminal`
`DELAY 1000`
`ENTER`
`DELAY 1000`

Any input or troubleshooting steps would be greatly appreciated.

Notes / possibly useful info:
- Before reformatting the partition i also got the mac unknown keyboard wizard a couple times
- Drive is acting as expected on windows machines
- I have access to Mac / Windows / Rasbian(debian) systems if needed to troubleshoot

krakrukra, 2020-11-15:
Previous issue #5 was in fact resolved by reformatting the drive and changing the text editor, the
person that created it contacted me in 2 different places, so our discussion continued outside of github.

When you were naming the drive as "USBDRIVE1" you were most likely setting the FAT volume label,
which is limited in length to 11 characters. This is certainly not the cause of your problem. "Ordinary
Flash Drive" is the drive name used in a BIOS menu, i guess your mac showed it because the drive
originally had no FAT label.

In your case I think you have done everything correctly up until the point where you created your payload
file. I remember that last time I tested default text editor on macos (TextEdit) it was adding a lot of weird
stuff into the text files, as if it is not a text editor but some office program. So, that made the payload files
created by it not readable by the device. You can try to install a different text editor on your mac,
eg. notepad++ and it should work. Or, you could make your payload file on eg. windows (notepad),
then use it on mac. If it works, than you know that text editor was in fact the problem.

Unknown keyboard wizard is an apple thing. This shows up whenever you use a keyboard that was not
made by apple. You could use VID/PID changing to avoid that (set these to values of some apple keyboard).

iwantmyhatback, 2020-11-15:
Unfortunately the issue is not from the text editor as i used a `touch` command and CLI `nano` to create the payload file, do you perhaps have any other suggestions for things to check that could be causing an issue?

Just an FYI for you though if you'd like to remove the formatting on your mac text editor you can go into the Text Edit preferences and change the format from rich text to plain text and i think that would remove any strange formatting on your machine!

krakrukra, 2020-11-15:
OK. Then check if you actually have a proper MBR partition table and you are formatting the first
partition, not the whole drive. This looks kind of weird:
> 0: FDisk_partition_scheme *100.9 MB disk2
> 1: DOS_FAT_32 ⁨USBDRIVE1⁩ 100.9 MB disk2s1

If I understand this correctly, full disk size and first partition size are the same, which should not normally
be the case. Usually partition table tools leave like 1 or 2 MiB of free space after the MBR, so if you have a
single partition it is normally 94-95 MiB in size (full disk is 96MiB).

Since you have a windows machine, try doing this: https://youtu.be/jhsEZJUVx_E
Start following the video from 20 second mark, starting with a right click on windows button.
There, I select PocketAdmin's USB drive, erase all partitions and create a new one with FAT filesystem.

If your payloads still don't work, then it might be some weird filesystem error that formatting tools do
not fix for some reason. In this case, overwriting all data on the PocketAdmin's disk to 0xFF bytes could
help. Follow this video to install and use HxD hex editor:  https://youtu.be/aTmnEvwCHiA
Make sure to select the right drive before overwriting. After that, Follow steps from the first video again
and see it it solved the problem.

iwantmyhatback, 2020-11-16:
I was able to resolve using the first part of your response by formatting using the Windows Disk Manager, I guess that it partitions FAT differently than the Mac disk utility does. I have verified that the Mac disk utility was the issue by following that instruction on a second PocketAdmin from "Factory", just repartition and everything is good to go.

I realized before formatting the second PocketAdmin that the Mac was seeing the original partition as a Linux partition for some reason, so just leaving this information here for anyone with issues in the future (Use the Windows Disk Management Tool):

**Factory Default PocketAdmin Partition**
`/dev/disk2 (external, physical):`
`   #:                       TYPE NAME                    SIZE       IDENTIFIER`
`   0:     FDisk_partition_scheme                        *100.9 MB   disk2`
`   1:                      Linux ⁨⁩                        99.9 MB    disk2s1`

**Mac Disk Utility PocketAdmin Partition**
`/dev/disk2 (external, physical):`
`#: TYPE NAME SIZE IDENTIFIER`
`0: FDisk_partition_scheme *100.9 MB disk2`
`1: DOS_FAT_32 ⁨USBDRIVE1⁩ 100.9 MB disk2s1`

**Windows Disk Manager PocketAdmin Partition**
`/dev/disk3 (external, physical):`
`   #:                       TYPE NAME                    SIZE       IDENTIFIER`
`   0:     FDisk_partition_scheme                        *100.9 MB   disk3`
`   1:             Windows_FAT_16 ⁨NEW VOLUME⁩              99.6 MB    disk3s1`

Thanks for your help @krakrukra

Closed 2020-11-16.

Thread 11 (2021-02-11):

How to create new or edit existing keyboard layout ?

mrshellx, 2021-02-11:
Hello,
I want add new keyboard layout and edit existing one, in tr_TR layout some keys not printing (like '_ç_', '_ö_'), how can i do this ?

krakrukra, 2021-02-12:
Keyboard layout files are only used to translate ASCII-printable characters into correct
keycode + modifiers combination. Since the characters which you are trying to print are
not ASCII-printable, you will not be able to use them directly in payload files (eg. inside of
a STRING command). If you just want some way to type these characters in, you could
instead use the KEYCODE command. In your case you would use "KEYCODE 0x36" for "ö", and
"KEYCODE 0x37" for "ç" (you can also add modifiers like "SHIFT KEYCODE 0x37")
for mor information about keycodes, you can check out this document (pages 52 to 59):
https://usb.org/document-library/hid-usage-tables-121

Closed 2021-02-15.

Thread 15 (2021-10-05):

Whenever I try to eject the pocketadmin it reconnects

cccreng, 2021-10-05:
When I press the eject button, it disconnects then reconnects.
Also, the usb isn't executing payloads when it's plugged in.
I tried fixing it using dfusedemo (using the windows steps on https://github.com/krakrukra/PocketAdmin/wiki/bootloader), and it didn't fix it.

krakrukra, 2021-10-05:
Which OS are you using, and what is your payload script?

krakrukra, 2021-10-05:
and also, try reformatting the first partition on the device (with FAT16 or FAT32 filesystem)

krakrukra, 2021-10-05:
did it stop showing up after you used dfusedemo to update firmware? or did it work for a while after that?

krakrukra, 2021-10-05:
OK, maybe there was some problem with firmware flashing. Does the DFU interface show up
if you short together two holes before plugging in, like shown in the video at 9:20 timestamp?
https://www.youtube.com/watch?v=t0oajBFZcZY

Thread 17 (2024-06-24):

String type slowly in Windows 11

leomacin, 2024-06-24:
Pocketmadmin version 1300X types slowly and even stuck in the middle of String Command in Windows 11.
This is more clear in Windows 11 when you are typing on Notepad. It doesn't happen in Linux and Windows 10 or earlier.

krakrukra, 2024-06-30:
Just now noticed this open issue, oops. I will make some tests on a windows 11 PC and try to recreate
this problem and see what can be done. Meanwhile, you can try adding a "STRING_DELAY 1" command
to the beginning of payload.txt and check if it helps or not. Maybe try some other values too, eg 1, 2, 5, 10

krakrukra, 2024-07-06:
OK, so on my test machine with windows 11 everything works without any problem. Can you post
exactly the payload that you have that is getting stuck for you?

krakrukra, 2024-07-11:
Actually, after doing some more testing I managed to recreate this problem. This happens specifically on windows 11 version of notepad (not in runline window or powershell, etc). Sometimes typing gets stuck and continues  only when you press or hold a button on a normal keyboard. Seems like notepad on win 11 sometimes can not handle very fast typing. I artificially slowed it down with "STRING_DELAY 5" command inside my payload and
the problem is gone now.

Closed 2024-07-17.

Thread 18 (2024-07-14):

Placement of capacitors

ysard, 2024-07-14:
Hi, first of all, thank you for your great project;
I've studied the PCB and I think I've identified a few "problematic" capacitor placements.

- A 3V3 power rail exits the MCP7000 to the header pin 4 without passing through capacitor C2.
- Capacitor C6 is bypassed because the 3V3 rail touches pin 24 just before it.
- Same thing for C7 and pin 48

I recently encountered similar issues on a personal project.
Here are some doc :

    https://www.protoexpress.com/blog/decoupling-capacitor-placement-guidelines-pcb-design/
    https://www.protoexpress.com/blog/decoupling-capacitor-use/
    https://www.pcbbuy.com/news/Decoupling-Capacitor-Placement-PCB.html

Hoping this will be useful to you, even if the PCB is working correctly without these modifications.

krakrukra, 2024-07-15:
Sure. TBH, you are overthinking this by a lot. Highest frequency on any trace here is 12MHz, that is not super fast.
I could probably take most of the decoupling caps away completely and the circuit would work still.

And if you want it more specifically, then header pin 4 is not connected to anything during normal operation. It
can not draw any current and does not need decoupling. It can act as a source when a hardware programmer
device is connected, hence C8 is in place to act as one more bulk decoupling capacitor on the other side of PCB.

I also see that you suggest C6 and C7 are bypassed somehow. Not really. Main power source from host PC through
MCP1700, and bulk decoupling caps, and local decoupling caps are all connected in parallel. And all can act as a
temporary voltage source. Local decoupling caps provide the path with smallest impedance at high frequency. If I
make the 3.3V trace first go to a pad under C6 then to MCU pin 24 it will not decrease impedance further than it
is. Still the same length of trace between C6 and MCU pin 24, still the same loop area for current sourced from C6
through the MCU and then to load that MCU drives and back to C6 (hence the same inductance).

ysard, 2024-07-15:
Thank you for your reply and explanations, in fact I think there's quite a bit of FUD about the position of the capacitors.

I understand your arguments, especially since the circuit doesn't work at very high frequencies.
If you have any documentation I'd be happy to read it ;)

krakrukra, 2024-07-15:
Yes, it's kind of a complicated topic, easy to get confused. And it's not like I am the greatest expert on this
either, I was reading articles much like you found, watching tutorials and stuff like that. Also read one
book called "Electromagnetic Compatibility Engineering" I think it had a section on decoupling caps
which was helpful.

ysard, 2024-07-16:
Thanks for the recommendation, there's indeed a long chapter on the subject that I'm currently reading.

I guess you can close the issue ;)

Closed 2024-07-17.

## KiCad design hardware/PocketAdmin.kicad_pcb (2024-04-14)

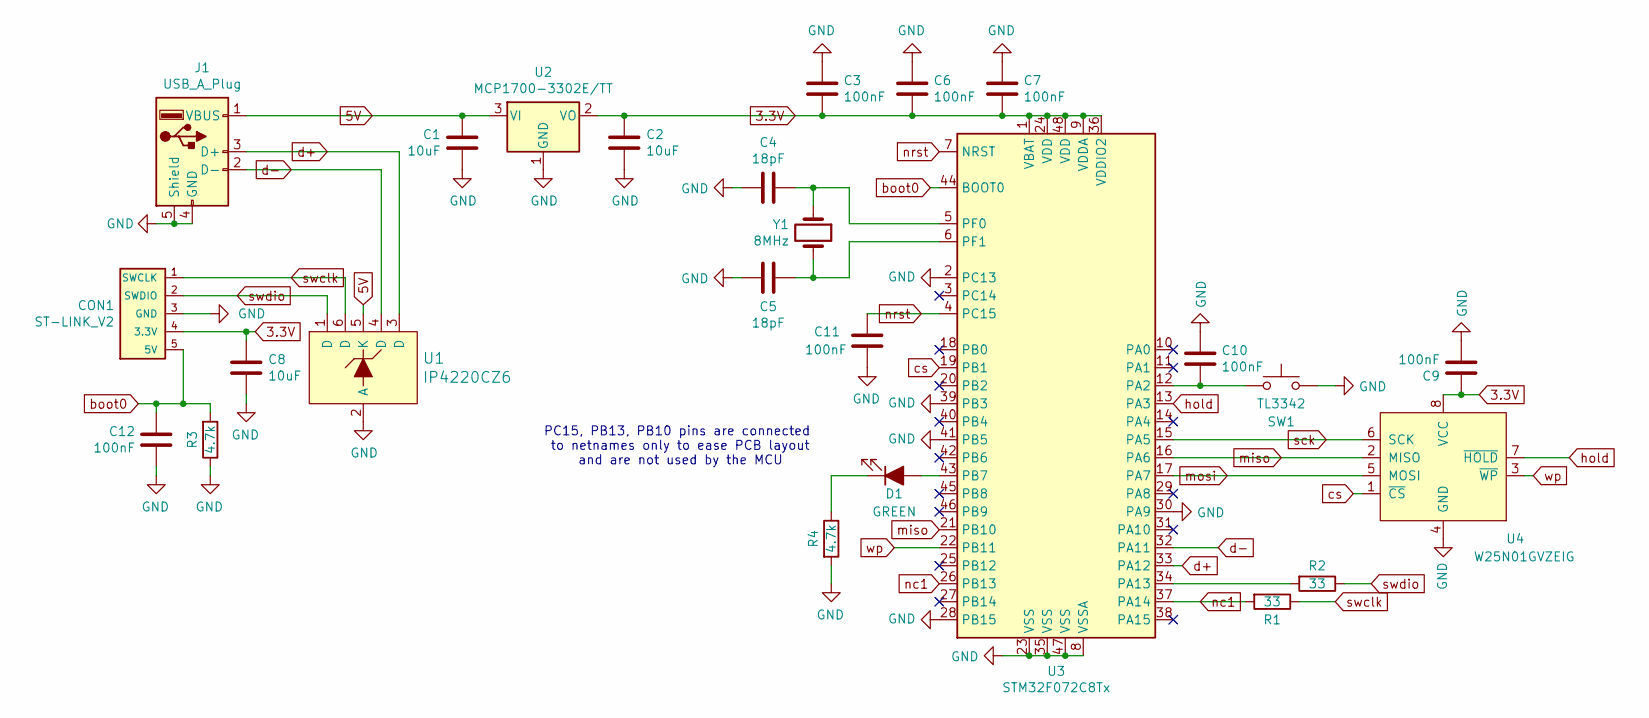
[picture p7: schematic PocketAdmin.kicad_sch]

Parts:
C1, C2, C8: 10uF; C_0805_2012Metric
C3, C6, C7, C9, C10, C11, C12: 100nF; C_0603_1608Metric
C4, C5: 18pF; C_0603_1608Metric
CON1: ST-LINK_V2; PinHeader_1x05_P2.54mm_Vertical
D1: GREEN; LED_0603_1608Metric
J1: USB_A_Plug; USB_A_CNCTech_1001-011-01101_Horizontal
R1, R2: 33; R_0603_1608Metric
R3, R4: 4.7k; R_0603_1608Metric
SW1: TL3342; SW_SPST_TL3342
U1: IP4220CZ6; TSOP-6_1.65x3.05mm_P0.95mm
U2: MCP1700-3302E/TT; SOT-23
U3: STM32F072C8Tx; LQFP-48_7x7mm_P0.5mm
U4: W25N01GVZEIG; WSON-8_8x6mm
Y1: 8MHz; Crystal_SMD_5032-2Pin_5.0x3.2mm

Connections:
3.3V: C2.1, C3.2, C6.2, C7.2, C8.1, C9.1, CON1.4 (3.3V), U2.2 (VO), U3.1 (VBAT), U3.9 (VDDA), U3.24 (VDD), U3.36 (VDDIO2), U3.48 (VDD), U4.8 (VCC)
5V: C1.1, J1.1 (VBUS), U1.5 (K), U2.3 (VI)
GND: C1.2, C2.2, C3.1, C4.2, C5.2, C6.1, C7.1, C8.2, C9.2, C10.1, C11.2, C12.1, CON1.3 (GND), J1.4 (GND), J1.5 (Shield), R3.1, R4.2, SW1.2, U1.2 (A), U2.1 (GND), U3.2 (PC13), U3.8 (VSSA), U3.23 (VSS), U3.28 (PB15), U3.30 (PA9), U3.35 (VSS), U3.39 (PB3), U3.41 (PB5), U3.47 (VSS), U4.4 (GND), U4.9 (GND)
unnamed: C4.1, U3.5 (PF0), Y1.1
unnamed: C5.1, U3.6 (PF1), Y1.2
unnamed: C10.2, SW1.1, U3.12 (PA2)
unnamed: D1.1 (K), R4.1
unnamed: D1.2 (A), U3.43 (PB7)
unnamed: R2.2, U3.34 (PA13)
boot0: C12.2, CON1.5 (5V), R3.2, U3.44 (BOOT0)
cs: U3.19 (PB1), U4.1 (~CS)
d+: J1.3 (D+), U1.3 (D), U3.33 (PA12)
d-: J1.2 (D-), U1.4 (D), U3.32 (PA11)
hold: U3.13 (PA3), U4.7 (~HOLD)
miso: U3.16 (PA6), U3.21 (PB10), U4.2 (MISO)
mosi: U3.17 (PA7), U4.5 (MOSI)
nc1: R1.2, U3.26 (PB13), U3.37 (PA14)
nrst: C11.1, U3.4 (PC15), U3.7 (NRST)
sck: U3.15 (PA5), U4.6 (SCK)
swclk: CON1.1 (SWCLK), R1.1, U1.6 (D)
swdio: CON1.2 (SWDIO), R2.1, U1.1 (D)
wp: U3.22 (PB11), U4.3 (~WP)

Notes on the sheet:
PC15, PB13, PB10 pins are connected to netnames only to ease PCB layout and are not used by the MCU

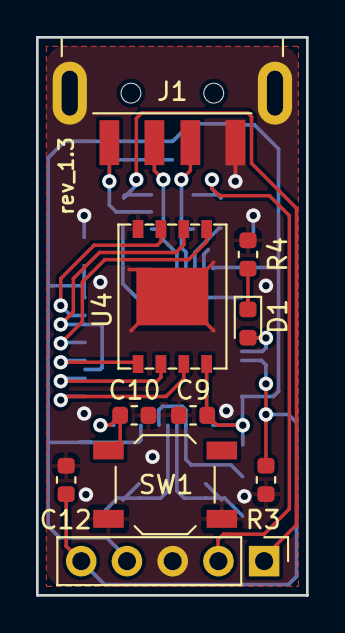
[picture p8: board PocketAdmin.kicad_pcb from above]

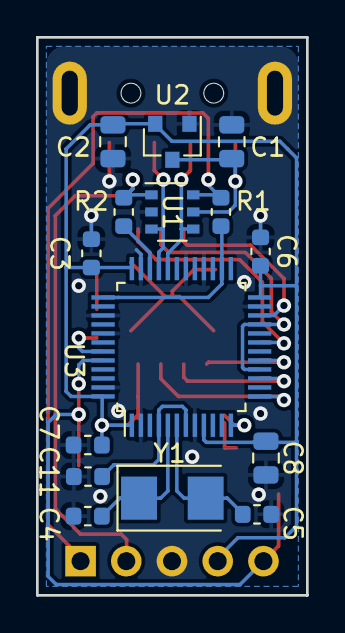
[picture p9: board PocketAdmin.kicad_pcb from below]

Board: 2 copper layers, 15.0 x 31.0 mm, 25 parts (15 on the bottom side), 22 nets.

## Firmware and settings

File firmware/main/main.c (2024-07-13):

#include "../cmsis/stm32f0xx.h"
#include "../usb/usb.h"
#include "../usb/hid_rodata.h"
#include "../fatfs/ff.h"
#include "../fatfs/diskio.h"

extern ControlInfo_TypeDef ControlInfo;
extern MSDinfo_TypeDef MSDinfo;
extern DeviceDescriptor_TypeDef DeviceDescriptor;
extern unsigned short StringDescriptor_1[13];

static char PayloadBuffer[2048] __attribute__(( aligned(2) ));//holds duckyscript commands to execute
static FATFS FATFSinfo;//holds info about filesystem on the medium
static FIL openedFileInfo_1;//holds info related to the first opened file
static FIL openedFileInfo_2;//holds info related to the second opened file
static unsigned int BytesRead;//holds the number of bytes that were successfully read with f_read()
static FRESULT FATFSresult;//holds return values of FATFS related funtions

static void readConfigFile(char* filename);
static void waitForInit();
static void setLEDon (unsigned char keycode, unsigned char bitmask);
static void setLEDoff(unsigned char keycode, unsigned char bitmask);
static unsigned short countCapsToggles(unsigned short toggleLimit);
static void runDuckyPayload(char* filename);
static void runDuckyCommand();
static void repeatDuckyCommands(unsigned int count);
static char checkKeyword(char* referenceString);
static unsigned int checkDecValue();
static unsigned int checkHexValue();
static void setFilename(char* newName);
static void setSerialNumber(char* newSerialNumber);
static void sendString(char* stringStart);
static void sendKBreport(unsigned short modifiers, unsigned int keycodes);
static void sendMSreport(unsigned int mousedata);
static void skipSpaces();
static void skipString();

static inline void delay_us(unsigned int delay) __attribute__((always_inline));
static void delay_ms(unsigned int delay);
static void restart_tim6(unsigned short time);
static void enter_bootloader();

static void saveKeyReflection();
static void saveOSfingerprint();
static void checkOSfingerprint();

volatile char KRbuffer[512];//holds data received via keystroke reflection
PayloadInfo_TypeDef PayloadInfo =
  {
    .DefaultDelay = 0,//if  DEFAULT_DELAY is not explicitly set, use 0ms value
    .StringDelay = 0,//if STRING_DELAY is not explicitly set, use 0ms value
    .PayloadPointer = (char*) &PayloadBuffer,//start interpreting commands at the beginning of PayloadBuffer
    .BytesLeft = 0,//nothing was saved in PayloadBuffer yet
    .RepeatStart = 0,//repeat start is at the beginning of the file
    .RepeatCount = 0xFFFFFFFF,//RepeatCount was not specified yet
    .HoldMousedata = MOUSE_IDLE,//no mouse activity present
    .HoldKeycodes= KB_Reserved,//no keycodes are applied    
    .HoldModifiers = MOD_NONE,//no modifiers are applied
    .KRbitNumber = 0,//write keystroke reflection data from the begginnig of KRbuffer
    .LEDstates = 0,//assume no LED's are ON yet
    .Filename = {0x00},//no target filename is specified yet
    .PayloadFlags = 0,//no payload specific flags are set
    .DeviceFlags = 0//no device wide flags are set
  };

//----------------------------------------------------------------------------------------------------------------------

int main()
{
  unsigned short toggleCount = 0;//holds number of times that capslock was switched on/off within a given toggle sequence
  
  //initialize W25N01GVZEIG flash memory chip, mount filesystem on the first partition, open and read payload.txt
  delay_ms(5);//wait until W25N01GVZEIG startup delay is over and it is able to accept commands
  __enable_irq();//enable interrupts globally (this is required for W25N01GVZEIG flash memory operations)
  
  if( f_mount(&FATFSinfo, "0:", 1) )//if no valid FAT is found
    {
      disk_initialize(0);//initialize flash memory for MSD use
      usb_init();//initialize USB
      
      while(1)
	{
	  sendKBreport(MOD_NONE, KB_Reserved);//send an empty report
	  
	  if(countCapsToggles(65535) > 19)//if there was 20 or more capslock toggles in a given sequence
	    { 
	      RCC->APB1RSTR |= (1<<23);//reset USB registers, detach from the USB bus
	      delay_ms(1000);//wait for 1000ms
	      RCC->APB1RSTR &= ~(1<<23);//deassert USB reset
	      enter_bootloader();//enter DFU mode right away
	    }
	}
    }
  else//if filesystem was successfully mounted
    { 
      f_chdir("0:/");
      readConfigFile("config.txt");
      
      usb_init();//initialize USB
      while(ControlInfo.OSfingerprintCounter < 10);//wait until OS fingerprint is collected      
      if(PayloadInfo.DeviceFlags & (1<<3)) waitForInit();
      
      if(PayloadInfo.DeviceFlags & (1<<2))//if there is a USE_FINGERPRINTER command in config.txt
	{
	  NVIC_DisableIRQ(31);//disable usb interrupt, so that MSD access and fatfs access do not collide      
	  saveOSfingerprint();//save collected OS fingerprint in /fingerdb/current.fgp
	  checkOSfingerprint();//set appropriate payload filename in PayloadInfo.Filename[]
	  f_chdir("0:/fgscript");//go to /fgscript/ directory
	  NVIC_EnableIRQ(31);//enable USB interrupt
	  
	  //unless explicitly disabled, run OS specific ON-INSERTION script
	  if( !(PayloadInfo.DeviceFlags & (1<<0)) ) runDuckyPayload(PayloadInfo.Filename);
	}
      else//if fingerprinter is disabled
	{
	  NVIC_DisableIRQ(31);//disable USB interrupt so that MSD and fatfs data access do not collide
	  f_chdir("0:/");//go to the root directory
	  NVIC_EnableIRQ(31);//enable USB interrupt
	  
	  //unless explicitly disabled, run default ON-INSERTION script
	  if( !(PayloadInfo.DeviceFlags & (1<<0)) ) runDuckyPayload("payload.txt");
	}
      
      while(1)
	{
	  sendKBreport(MOD_NONE, KB_Reserved);//send an empty keyboard report
	  sendMSreport(MOUSE_IDLE);//send an empty mouse report
	  
	  toggleCount = countCapsToggles(65535);//count number of capslock toggles in one sequence
	  
	  //if there was from 3 to 19 capslock toggles in a given sequence
	  if( (toggleCount > 2) && (toggleCount < 20) )
	    {
	      NVIC_DisableIRQ(31);//disable USB interrupt to prevent f_mount() and MSD access collision
	      FATFSresult  = f_mount(&FATFSinfo, "0:", 1);//remount the filesystem, just in case new on-demand scripts were added
	      FATFSresult |= f_chdir("0:/ondemand");//go to the /ondemand/ directory
	      setFilename("script__.txt");//set next payload filename to script__.txt
	      PayloadInfo.Filename[6] = 48 + toggleCount / 10;//set correct on-demand payload name
	      PayloadInfo.Filename[7] = 48 + toggleCount % 10;//set correct on-demand payload name
	      NVIC_EnableIRQ(31);//enable USB interrupt
	      
	      if(!FATFSresult) runDuckyPayload(PayloadInfo.Filename);//execute specified on-demand script
	    }
	  else if(toggleCount > 19)//if there was 20 or more capslock toggles in a given sequence
	    {
	      MSDinfo.LBAoffset = 0;//do not hide any blocks from MSD interface
	      MSDinfo.FakeCapacity = 0;//show real capacity
	      ControlInfo.EnumerationMode = 0;//set enumeration mode to default
	      MSDinfo.MSDflags &= ~(1<<4);//allow read and write MSD operations
	      
	      RCC->APB1RSTR |= (1<<23);//reset USB registers, detach from the USB bus
	      delay_ms(1000);//wait for 1000ms
	      RCC->APB1RSTR &= ~(1<<23);//deassert USB reset
	      if(PayloadInfo.DeviceFlags & (1<<3)) enter_bootloader();//if DFUmodeFlag is set
	      else                                 usb_init();//if DFUmode flag was not set
	      
	      NVIC_DisableIRQ(31);//disable USB interrupt to prevent race condition
	      __DSB();//make sure NVIC registers are updated before ISB is executed
	      __ISB();//make sure the latest NVIC setting is used immediately
	      PayloadInfo.DeviceFlags |= (1<<3);//set DFUmodeFlag
	      MSDinfo.MSDflags &= ~(1<<3);//clear MSD FirstReadFlag
	      NVIC_EnableIRQ(31);//enable USB interrupt again
	    }
	}
      
    }
  
  return 0;
}

//----------------------------------------------------------------------------------------------------------------------

//open a file called filename inside current directory and execute all pre-configuration commands inside
static void readConfigFile(char* filename)
{
  unsigned int commandStart = (unsigned int) &PayloadBuffer;//remember where start of command is
  unsigned int firstLBA;//holds first LBA of the first partition
  unsigned int LBAcount;//holds size of first partition in LBA
  unsigned char MSDbutton;//holds state of the MSD-only button (1 = pressed, 0 = released)
  
  //sample the state of MSD-only button at the time of insertion
  if( !(GPIOA->IDR & (1<<2)) ) MSDbutton = 1;
  else                         MSDbutton = 0;
  
  if( !f_open(&openedFileInfo_1, filename, FA_READ | FA_OPEN_EXISTING) )//if configuration file was successfully opened
    {
      f_read(&openedFileInfo_1, (char*) &PayloadBuffer, 512, &BytesRead);
      PayloadInfo.PayloadPointer = (char*) &PayloadBuffer;//move PayloadPointer back to start
      PayloadInfo.BytesLeft = BytesRead + 1;//one extra newline character will be appended to the end of payload script
      //always append a newline after config file contents; that prevents bricking the device by skipString() if there is no newline in config.txt
      PayloadBuffer[BytesRead] = 0x0A;
      f_close(&openedFileInfo_1);
      
      //run pre-configuration commands from specified configuration file
      while(PayloadInfo.BytesLeft)
	{
	  commandStart = (unsigned int) PayloadInfo.PayloadPointer;//remember where start of current command is
	  skipSpaces();
	  
	  
	       if( checkKeyword("VID 0x") )     {DeviceDescriptor.idVendor  = (unsigned short) checkHexValue();}
	  else if( checkKeyword("PID 0x") )     {DeviceDescriptor.idProduct = (unsigned short) checkHexValue();}
	  else if( checkKeyword("SERIAL ") )    {setSerialNumber(PayloadInfo.PayloadPointer);}
	  else if( checkKeyword("MASS_ERASE") ) {mass_erase(); NVIC_SystemReset();}
	  else if( (MSDbutton == 0) && checkKeyword("READ_ONLY_MODE") ) {MSDinfo.MSDflags |= (1<<4);}
	  else if( (MSDbutton == 0) && checkKeyword("HID_ONLY_MODE") )  {ControlInfo.EnumerationMode = 1;}
	  
	  else if( (MSDbutton == 0) && checkKeyword("USE_HIDDEN_REGION") )
	    {
	      //read LBA 0 into an unused area of PayloadBuffer
	      disk_read(0, (unsigned char*) &PayloadBuffer + 1024, 0, 1);
	      
	      //if a valid MBR signature is found, set LBAoffset value based on first partition entry
	      if( (PayloadBuffer[1534] == 0x55) && (PayloadBuffer[1535] == 0xAA) )
		{
		  firstLBA  = *( (unsigned short*) (&PayloadBuffer[1478]) ) <<  0;
		  firstLBA |= *( (unsigned short*) (&PayloadBuffer[1480]) ) << 16;
		  LBAcount  = *( (unsigned short*) (&PayloadBuffer[1482]) ) <<  0;
		  LBAcount |= *( (unsigned short*) (&PayloadBuffer[1484]) ) << 16;
		  //if LBAoffset is 16MiB of less, hide the specified LBA's
		  if( (firstLBA + LBAcount) <= 32768 ) MSDinfo.LBAoffset = firstLBA + LBAcount;
		}
	    }
	  else if( (MSDbutton == 0) && checkKeyword("SHOW_FAKE_CAPACITY ") )
	    {
	      MSDinfo.FakeCapacity = checkDecValue();//read fake capacity value (in MiB)
	      //only allow fake capacity from 97MiB to 64GiB
	      if(MSDinfo.FakeCapacity > 65535) MSDinfo.FakeCapacity = 0;
	      if(MSDinfo.FakeCapacity < 97)    MSDinfo.FakeCapacity = 0;
	    }
	  else if( checkKeyword("FIRST_INSERT_ONLY") )
	    {
	      //if 0:/noinsert file is already present, set NoInsertFlag
	      if( !f_open(&openedFileInfo_1, "noinsert", FA_READ | FA_OPEN_EXISTING ) ) PayloadInfo.DeviceFlags |= (1<<0);
	      //if 0:/noinsert file is not present, create noinsert file, but keep NoInsertFlag cleared
	      else f_open(&openedFileInfo_1, "noinsert", FA_WRITE | FA_CREATE_ALWAYS);
	      
	      f_close(&openedFileInfo_1);
	    }
	  else if( checkKeyword("USE_FINGERPRINTER") )
	    {
	      f_mkdir("0:/fgscript");
	      f_mkdir("0:/fingerdb");
	      PayloadInfo.DeviceFlags |= (1<<2);
	    }
	  else if( checkKeyword("USE_LAYOUT ") )
	    {	      	      
	      f_mkdir("0:/kblayout");//create /kblayout/
	      f_chdir("0:/kblayout");//go to /kblayout/ directory
	      setFilename(PayloadInfo.PayloadPointer);
	      
	      //load new keymap from the specified file
	      if( !f_open( &openedFileInfo_1, (char*) &(PayloadInfo.Filename), FA_READ | FA_OPEN_EXISTING) )
		{
		  f_read( &openedFileInfo_1, (unsigned char*) &Keymap, 107, &BytesRead );
		  f_close( &openedFileInfo_1 );
		}
	    }	  	 
	  
	  //go to the next line
	  skipString();
	  if( PayloadInfo.PayloadPointer < ((char*) &PayloadBuffer + 2047) ) PayloadInfo.PayloadPointer++;
	  else PayloadInfo.PayloadPointer = (char*) &PayloadBuffer;
	  
	  PayloadInfo.BytesLeft = PayloadInfo.BytesLeft - ((unsigned int) PayloadInfo.PayloadPointer - commandStart);
	}
    }
  
  //if MSD-only button was pressed set NoInsertFlag
  if(MSDbutton) PayloadInfo.DeviceFlags |= (1<<0);
  
  return;
}

static void waitForInit()
{
  restart_tim6(50);//set TIM6 to count for 50ms
  while(TIM6->CR1 & (1<<0))//keep all keys released until TIM6 runs out
    {
      sendKBreport(MOD_NONE, KB_Reserved);//send an empty report
      delay_ms(10);//wait for 10 milliseconds before sending new report
    }
  
  setLEDon(KB_CAPSLOCK, 0x02); //keep toggling capslock until it is turned on 
  setLEDoff(KB_CAPSLOCK, 0x02);//keep toggling capslock until it is turned off
  
  if(PayloadInfo.LEDstates & (1<<1))//if late arriving capslock was detected, toggle capslock for one more time
    {
      sendKBreport(MOD_NONE, KB_CAPSLOCK);//press capslock key
      delay_ms(10);//keep capslock pressed for 10 milliseconds
      sendKBreport(MOD_NONE, KB_Reserved);//send an empty report
    }
  
  //unless HID-only mode is used, make sure MSD interface has received at least 1 read command
  while( (ControlInfo.EnumerationMode == 0) && !(MSDinfo.MSDflags & (1<<3)) );
  
  return;
}

//keycode must be KB_CAPSLOCK, KB_SCROLLLOCK or KP_NUMLOCK, bitmask must match LED from keycode
static void setLEDon (unsigned char keycode, unsigned char bitmask)
{
  unsigned char LEDon = PayloadInfo.LEDstates & bitmask;//holds nonzero value if selected LED is ON
  
  while( !LEDon )//keep going until selected LED is turned on
    {
      restart_tim6(100);//set TIM6 to count for 100ms
      while( (TIM6->CR1 & (1<<0)) && !LEDon )//keep selected key pressed until TIM6 runs out or LED turns on
	{
	  sendKBreport(MOD_NONE, keycode);//press selected key
	  delay_ms(10);//wait for 10 milliseconds before sending new report
	  LEDon = PayloadInfo.LEDstates & bitmask;//sample selected LED state
	}
      
      restart_tim6(200);//set TIM6 to count for 200ms
      while( (TIM6->CR1 & (1<<0)) && !LEDon )//keep selected key released until TIM6 runs out or LED turns on
	{
	  sendKBreport(MOD_NONE, KB_Reserved);//send an empty report
	  delay_ms(10);//wait for 10 milliseconds before sending new report
	  LEDon = PayloadInfo.LEDstates & bitmask;//sample selected LED state
	}
    }
  
  restart_tim6(50);//set TIM6 to count for 50ms
  while(TIM6->CR1 & (1<<0))//keep all keys released until TIM6 runs out
    {
      sendKBreport(MOD_NONE, KB_Reserved);//send an empty report
      delay_ms(10);//wait for 10 milliseconds before sending new report
    }
  
  return;
}

//keycode must be KB_CAPSLOCK, KB_SCROLLLOCK or KP_NUMLOCK, bitmask must match LED from keycode
static void setLEDoff (unsigned char keycode, unsigned char bitmask)
{
  unsigned char LEDon = PayloadInfo.LEDstates & bitmask;//holds nonzero value if selected LED is ON
  
  while( LEDon )//keep going until selected LED is turned off
    {
      restart_tim6(100);//set TIM6 to count for 100ms
      while( (TIM6->CR1 & (1<<0)) && LEDon )//keep selected key pressed until TIM6 runs out or LED turns off
	{
	  sendKBreport(MOD_NONE, keycode);//press selected key
	  delay_ms(10);//wait for 10 milliseconds before sending new report
	  LEDon = PayloadInfo.LEDstates & bitmask;//sample selected LED state
	}
      
      restart_tim6(1010);//start TIM6, wait up to 1010ms for host to acknowledge capslock press event (if not, try again)
      while( (TIM6->CR1 & (1<<0)) && LEDon )//keep capslock released until TIM6 runs out or CAPS LED turns off
	{
	  sendKBreport(MOD_NONE, KB_Reserved);//send an empty report
	  delay_ms(10);//wait for 10 milliseconds before sending new report
	  LEDon = PayloadInfo.LEDstates & bitmask;//sample selected LED state
	}
    }
  
  restart_tim6(50);//set TIM6 to count for 50ms
  while(TIM6->CR1 & (1<<0))//keep all keys released until TIM6 runs out
    {
      sendKBreport(MOD_NONE, KB_Reserved);//send an empty report
      delay_ms(10);//wait for 10 milliseconds before sending new report
    }
  
  return;
}

static unsigned short countCapsToggles(unsigned short toggleLimit)
{
  unsigned short toggleCount = 0;//holds number of times that capslock was switched on/off    
  unsigned char oldCAPSstate;//holds previous sampled value of capslock LED state
  unsigned char newCAPSstate;//holds latest   sampled value of capslock LED state
  
  restart_tim6(1010);//start capslock sequence timer, run for 1010ms
  oldCAPSstate = PayloadInfo.LEDstates & (1<<1);//sample capslock LED state at the start
  
  //keep going until capslock sequence timer runs out or toggleLimit is reached
  while( (TIM6->CR1 & (1<<0)) && (toggleCount < toggleLimit) )
    {
      //have a short delay before sampling new CAPS state again
      delay_ms(1);//wait for 1 millisecond
      garbage_collect();//erase an invalid block if found
      delay_ms(1);//wait for 1 millisecond
      newCAPSstate = PayloadInfo.LEDstates & (1<<1);//sample new CAPS state
      
      //if capslock LED state have changed since previous sample
      if( oldCAPSstate != newCAPSstate )
	{
	  restart_tim6(1010);//restart capslock toggle timer, run for 1010ms
	  toggleCount++;//one more capslock toggle event was detected
	}

      oldCAPSstate = newCAPSstate;//remember current CAPS state for the next comparison
    }
  
  return toggleCount;
}

//open a file called filename inside current directory and execute all ducky commands inside
static void runDuckyPayload(char* filename)
{
  unsigned char replaceFlag = 0;//will be set to 1 every time there is a need to replace some data in PayloadBuffer
  
  //reinitialize PayloadInfo variables which are script specific
  PayloadInfo.DefaultDelay = 0;
  PayloadInfo.StringDelay = 0;
  PayloadInfo.PayloadPointer = (char*) &PayloadBuffer;
  PayloadInfo.BytesLeft = 0;
  PayloadInfo.RepeatStart = 0;
  PayloadInfo.RepeatCount = 0xFFFFFFFF;
  PayloadInfo.HoldMousedata = MOUSE_IDLE;
  PayloadInfo.HoldKeycodes = KB_Reserved;
  PayloadInfo.HoldModifiers = MOD_NONE;
  PayloadInfo.KRbitNumber = 0;
  PayloadInfo.PayloadFlags = 0;
  
  NVIC_DisableIRQ(31);//disable usb interrupt, so f_open() and MSD access do not collide
  FATFSresult = f_open(&openedFileInfo_1, filename, FA_READ | FA_OPEN_EXISTING);//try to read the specified file
  NVIC_EnableIRQ(31);//enable usb interrupt
  
  //if appropriate payload file was successfully opened, run ducky interpreter
  if( !FATFSresult )
    {
      NVIC_DisableIRQ(31);//disable usb interrupt, so f_read() and MSD access do not collide
      f_read(&openedFileInfo_1, (char*) &PayloadBuffer, 2048, &BytesRead );
      PayloadInfo.BytesLeft = BytesRead + 1;//one extra newline character will be appended to the end of payload script
      if(BytesRead < 2048) PayloadBuffer[BytesRead] = 0x0A;//if end of file is detected, add an extra newline
      NVIC_EnableIRQ(31);//enable usb interrupt
      
      //keep executing commands until end of file is reached
      while(PayloadInfo.BytesLeft)
	{ 
	  //if at least half of PayloadBuffer was processed and can now be replaced with new data
               if( !(PayloadInfo.PayloadFlags & (1<<0)) && (PayloadInfo.PayloadPointer >= ((char*) &PayloadBuffer + 1024)) ) replaceFlag = 1;
	  else if(  (PayloadInfo.PayloadFlags & (1<<0)) && (PayloadInfo.PayloadPointer <  ((char*) &PayloadBuffer + 1024)) ) replaceFlag = 1;
	  
	  if(replaceFlag)//if some 1024 byte block was completely processed
	    {
	      NVIC_DisableIRQ(31);//disable usb interrupt, so f_read() and MSD access do not collide
	      f_read( &openedFileInfo_1, (char*) &PayloadBuffer + (PayloadInfo.PayloadFlags % 2) * 1024, 1024, &BytesRead );//try to read next 1024 bytes of payload
	      PayloadInfo.BytesLeft = PayloadInfo.BytesLeft + BytesRead;
	      if(BytesRead < 1024) PayloadBuffer[ (PayloadInfo.PayloadFlags % 2) * 1024 + BytesRead ] = 0x0A;//if end of file is detected, add an extra newline
	      
	      PayloadInfo.PayloadFlags ^= (1<<0);//commands are now being executed from the other half of PayloadBuffer
	      replaceFlag = 0;//set replaceFlag back to 0
	      NVIC_EnableIRQ(31);//enable usb interrupt again
	    }
	  
	  runDuckyCommand();//execute one line of ducky script, subtract number of executed bytes from BytesLeft
	}
    }
  
  NVIC_DisableIRQ(31);//disable usb interrupt, so f_close() and MSD access do not collide
  f_close(&openedFileInfo_1);//close the specified file
  NVIC_EnableIRQ(31);//enable usb interrupt
  
  return;
}
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

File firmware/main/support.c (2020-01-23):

#include "../cmsis/stm32f0xx.h"

extern int main();
extern void usb_handler() __attribute__((interrupt));
extern void dma_handler() __attribute__((interrupt));

static void startup();
static inline void initialize_data(unsigned int* from, unsigned int* data_start, unsigned int* data_end) __attribute__((always_inline));
static inline void initialize_bss(unsigned int* bss_start, unsigned int* bss_end) __attribute__((always_inline));

static void default_handler() __attribute__((interrupt));
static void    tim7_handler() __attribute__((interrupt));

//these symbols are declared in the linker script
extern unsigned int __data_start__;//start of .data section in RAM
extern unsigned int __data_end__;//end of .data section in RAM
extern unsigned int __bss_end__;//end of .bss section in RAM
extern unsigned int __text_end__;//end of .text section in ROM

void* vectorTable[48] __attribute__(( section(".vectab,\"a\",%progbits@") )) =
  {
    (void*)0x20003FFC,//initial main SP value (16kB RAM size)
    (void*)&startup,//reset vector
    (void*)&default_handler,//NMI
    (void*)&default_handler,//HardFault
    (void*)0x00000000,//reserved
    (void*)0x00000000,//reserved
    (void*)0x00000000,//reserved
    (void*)0x00000000,//reserved
    (void*)0x00000000,//reserved
    (void*)0x00000000,//reserved
    (void*)0x00000000,//reserved
    (void*)&default_handler,//SVCall
    (void*)0x00000000,//reserved
    (void*)0x00000000,//reserved
    (void*)&default_handler,//PendSV
    (void*)&default_handler,//SysTick
    (void*)0x00000000,//IRQ0
    (void*)0x00000000,//IRQ1
    (void*)0x00000000,//IRQ2
    (void*)0x00000000,//IRQ3
    (void*)0x00000000,//IRQ4
    (void*)0x00000000,//IRQ5
    (void*)0x00000000,//IRQ6
    (void*)0x00000000,//IRQ7
    (void*)0x00000000,//IRQ8
    (void*)0x00000000,//IRQ9 
    (void*)&dma_handler,//IRQ10
    (void*)0x00000000,//IRQ11
    (void*)0x00000000,//IRQ12
    (void*)0x00000000,//IRQ13
    (void*)0x00000000,//IRQ14
    (void*)0x00000000,//IRQ15
    (void*)0x00000000,//IRQ16
    (void*)0x00000000,//IRQ17
    (void*)&tim7_handler,//IRQ18
    (void*)0x00000000,//IRQ19
    (void*)0x00000000,//IRQ20
    (void*)0x00000000,//IRQ21
    (void*)0x00000000,//IRQ22
    (void*)0x00000000,//IRQ23
    (void*)0x00000000,//IRQ24
    (void*)0x00000000,//IRQ25
    (void*)0x00000000,//IRQ26
    (void*)0x00000000,//IRQ27
    (void*)0x00000000,//IRQ28
    (void*)0x00000000,//IRQ29
    (void*)0x00000000,//IRQ30
    (void*)&usb_handler//IRQ31
  };

//copies initialized static variable values from ROM to RAM
static inline void initialize_data(unsigned int* from, unsigned int* data_start, unsigned int* data_end)
{
  while(data_start < data_end)
    {
      *data_start = *from;
      data_start++;
      from++;
    }
}

//writes to zero uninitialized static variable values in RAM
static inline void initialize_bss(unsigned int* bss_start, unsigned int* bss_end)
{
  while(bss_start < bss_end)
    {
      *bss_start = 0x00000000U;
      bss_start++;
    }
}

//the very first function that the CPU will run
static void startup()
{
  RCC->AHBENR |= (1<<18)|(1<<17)|(1<<0);//enable GPIOA, GPIOB, DMA clocks
  RCC->APB1ENR |= (1<<5)|(1<<4)|(1<<0);//enable TIM7, TIM6, TIM2 clocks
  RCC->APB2ENR |= (1<<12);//enable SPI1 clock
  
  GPIOB->MODER |= (1<<22)|(1<<14)|(1<<2);//PB11, PB7, PB1 are outputs
  GPIOB->BSRR = (1<<11)|(1<<1);//pull PB11, PB1 high (WP and SPI1 CS signals)  
  GPIOA->MODER |= (1<<15)|(1<<13)|(1<<11)|(1<<6);//PA3 is output; PA7, PA6, PA5 are in alternate function mode (SPI1)
  GPIOA->BSRR = (1<<3);//pull PA3 high (HOLD signal)
  GPIOA->PUPDR |= (1<<4);//enable pullup at PA2
  
  FLASH->ACR = (1<<4)|(1<<0);//enable prefetch buffer and insert 1 wait state for flash read access (because SYSCLK will be 48MHz)  
  
  RCC->CR |= (1<<19)|(1<<16);//enable HSE clock, clock security system
  while( !(RCC->CR & (1<<17)) );//wait until HSE is ready
  RCC->CFGR |= (1<<20)|(1<<16);//derive PLL clock from HSE, multiply HSE by 6 (8MHz * 6 = 48MHz)
  RCC->CR |= (1<<24);//enable PLL
  
  initialize_data(&__text_end__, &__data_start__, &__data_end__);
  initialize_bss(&__data_end__, &__bss_end__);
  
  while( !(RCC->CR & (1<<25)) );//wait until PLL is ready
  RCC->CFGR |= (1<<1);//set PLL as system clock  
  while( !((RCC->CFGR & 0x0F) == 0b1010) );//wait until PLL is used as system clock
  RCC->CR &= ~(1<<0);//disable HSI clock
  
  main();
  
  NVIC_SystemReset();//if main() ever returns reset MCU
  return;
}

//default IRQ handler initiates system reset
static void default_handler()
{
  NVIC_SystemReset();
  return;
}

//TIM7 is used for driving flash memory status LED
static void tim7_handler()
{
  GPIOB->BSRR = (1<<23);//turn the status LED off
  TIM7->SR = 0;//clear the overflow interrupt flag
  
  return;
}

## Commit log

2019-05-22 added OS fingerprinter
2019-05-29 documetation update
    [config.txt]
2019-05-30 small layout update
    [PocketAdmin-B.Cu.gbr, PocketAdmin-B.Mask.gbr, PocketAdmin-B.SilkS.gbr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]
2019-07-03 replaced tantalum capacitors with MLCC
    [PocketAdmin-B.Cu.gbr, PocketAdmin-B.Mask.gbr, PocketAdmin-B.SilkS.gbr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]
2019-07-06 added panelised verison of PCB
    [PocketAdmin.kicad_pcb, PocketAdmin.sch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]
2019-07-06 added panelised version of PCB
2019-07-08 changed pad connection from solid to thermal
    [PocketAdmin-B.Cu.gbr, PocketAdmin-B.Mask.gbr, PocketAdmin-B.SilkS.gbr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]
2019-07-23 fixed a critical bug that led to device being bricked when config.txt had no newline at the end
    [main.c]
2019-08-11 better error handling for MSD interface
    [usb.c]
2019-08-19 better explaination for MSD-only button use
2019-09-30 big speed and FTL update, see github issue
    [main.c, support.c, usb.c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]
2019-10-21 updated example payloads
    [PocketAdmin-B.Cu.gbr, PocketAdmin-B.Mask.gbr, PocketAdmin-B.SilkS.gbr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]
2019-10-21 BOM.txt fix
    [PocketAdmin.sch]
2019-10-26 new example payload
    [config.txt]
2020-01-23 first testing release of 1.3 revision
    [PocketAdmin-B.Cu.gbr, PocketAdmin-B.Mask.gbr, PocketAdmin-B.SilkS.gbr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]
2020-01-24 fix in dynamic startup delay
    [main.c, usb.c]
2020-02-03 documentation update
    [config.txt]
2020-02-15 replaced device photos
2020-04-25 some documentation fixes
    [PocketAdmin.sch]
2020-06-12 new payload updates
    [config.txt]
2020-06-18 insert.ps1 will now delete cookies
2020-11-22 changed NRST capacitor
    [PocketAdmin.kicad_pcb, PocketAdmin.sch]
2021-03-03 bugfix update, improved MAC compatibility
    [main.c, usb.c, usb.h]
2021-08-11 prevent interpreter from freezing on error
    [main.c, usb.h]
2022-05-07 added keypad and LED control commands
    [config.txt]
2022-10-26 payload update
    [PocketAdmin.sch]
2023-03-01 updated openocd scripts
    [stlink.cfg, stm32f0x.cfg]
2023-04-28 eject fix + keystroke reflection
    [config.txt]
2023-11-15 move to newer toolchain versions
    [PocketAdmin.kicad_pcb, PocketAdmin.kicad_sch, PocketAdmin.sch]
2024-02-10 added HID-only powershell payloads
    [config.txt]
2024-02-13 add HID file exfiltration payload
    [config.txt]
2024-04-11 tiny PCB change to simplify manufacturing
    [PocketAdmin-B.Cu.gbr, PocketAdmin-B.Mask.gbr, PocketAdmin-B.SilkS.gbr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]
